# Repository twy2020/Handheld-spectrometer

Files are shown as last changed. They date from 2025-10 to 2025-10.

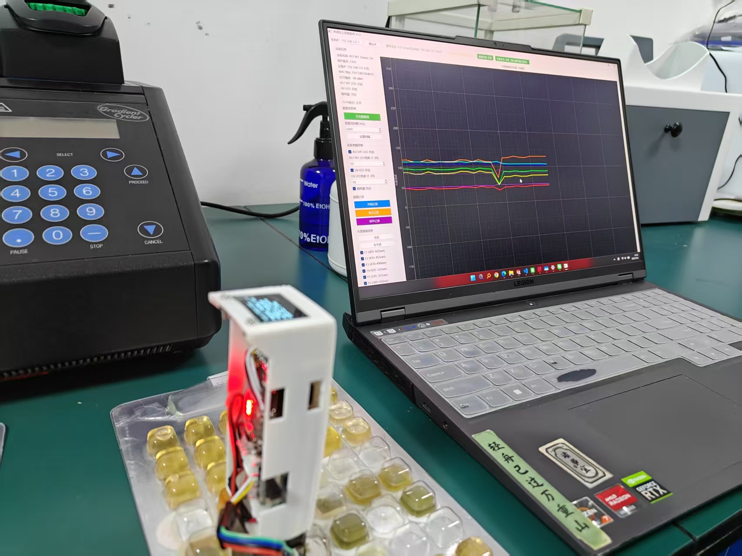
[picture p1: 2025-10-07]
pic/test_2.jpg

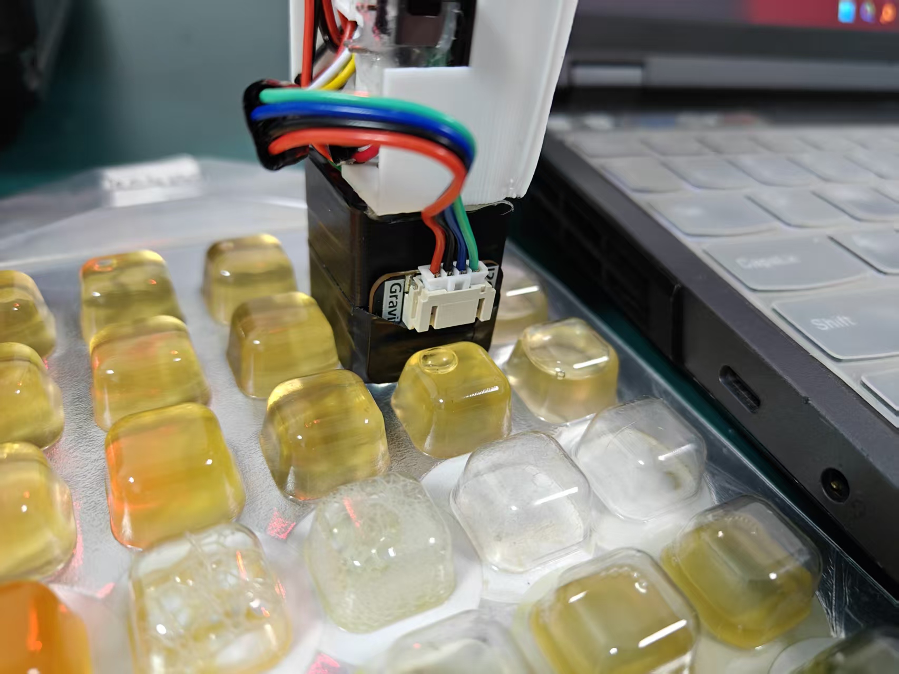
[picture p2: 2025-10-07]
pic/test_1.jpg

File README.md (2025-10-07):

# Smart Spectrometer System - Setup and Usage Guide
[README-中文](https://github.com/twy2020/Handheld-spectrometer/blob/main/README-CN.md)
## 1. Hardware Components List

Please prepare the following modules required for setup according to this list:

| Component | Model/Specification | Description |
| :--- | :--- | :--- |
| Spectral Sensor | RFRobot AS7341 (with built-in LED) | 11-channel visible light spectral sensor, including 8 optical channels, 1 clear channel, and 1 near-infrared channel |
| Main Controller | ESP32C3 Super Mini | Single-core processor with integrated WiFi (Required) |
| Display | SSD1306 128×64 OLED | Displays real-time spectral data, system status, and menu interface |
| UV Illumination System | UV LED 365nm x3 | Provides stable auxiliary light source for detection |
| UV LED Driver Board | CN5711 PWM LED Driver Board | Used to drive and adjust UV LEDs |
| Buzzer | Passive Buzzer (3.3V drive) | Optional, for device operation prompts |
| Power Bank | 3.7V Lithium Polymer Battery | Provides offline power for the device |
| Type-C Charging Module | Any module supporting Type-C interface and 5V output | Provides universal Type-C charging functionality |
| Battery Charge/Discharge Management Module | Any module supporting LiPo battery charge/discharge | Manages charging and passthrough charging for the 3.7V battery |
| Connecting Wires | Suitable insulated wires | For electrical connections between modules |
| Circuit Substrate | Perfboard or Custom PCB | Choose the circuit carrier method based on needs |

## 2. Required Tools

**Essential Tools:**

- Soldering Iron, Solder Wire, Flux
- Wire Strippers, Scissors, Measuring Tools
- Hot Glue Gun
- Multimeter

**Optional Tools:**

- Oscilloscope (Non-essential)
- 3D Printer (Non-essential)

## 3. Hardware Assembly

### 3.1 Circuit Soldering

Please solder all components according to the module connection diagram.
hardware

### 3.2 Enclosure Fabrication

The "3D" directory in the project files contains two model files that can be used to create the device enclosure, enhancing the product-like appearance.
3D

## 4. Device Firmware Flashing

### 4.1 Software Environment Configuration

**Software to Install:**

1.  CH341 Serial Port Driver
2.  Arduino IDE

**Arduino IDE Installation Steps:**

-   Visit the official website to download the latest Arduino IDE: https://www.arduino.cc/en/software
-   Install and launch the Arduino application
-   Add ESP32 board support

**Method for Adding ESP32 Board:**

1.  Go to File → Preferences
2.  Add the following URL in "Additional Boards Manager URLs":
    ```
    https://raw.githubusercontent.com/espressif/arduino-esp32/gh-pages/package_esp32_index.json
    ```
3.  Go to Tools → Board → ESP32 Arduino, select "ESP32C3 Dev Module"
4.  Go to Tools → Port, select the serial port corresponding to the ESP32C3 SuperMini
5.  **Important**: Go to Tools → USB CDC On Boot, set it to "Enable" (otherwise USB serial communication will not work)

### 4.2 Firmware Flashing Steps

1.  Open the `Spectrometer_v2.ino` file from the project using Arduino IDE
2.  Connect the ESP32C3 Super Mini to the computer via a USB cable
3.  Select the correct Port and Board type (ESP32C3 Dev Module)
4.  Click the "Upload" button and wait for the process to complete

## 5. PC Software Installation

### 5.1 Python Environment Configuration

**Installation Method 1: From Python Official Website**

-   Download and install Python 3.12: https://www.python.org/downloads/release/python-3120/

**Installation Method 2: Via Anaconda**

-   Download Anaconda: https://www.anaconda.com/download

**Note**: Please ensure that Python or Conda has been added to the system environment variables so they can be used directly in the terminal.

### 5.2 Installing Dependencies

**Installation using Conda environment:**

```bash
conda create -n SpDevice-PC python=3.12
conda activate SpDevice-PC
pip install PyQT5 pyqtgraph pyqt5-tools pandas
```

**Installation using Python environment:**

```bash
pip install PyQT5 pyqtgraph pyqt5-tools pandas
```

### 5.3 Starting the Software

Run the following command in the configured Conda environment or system Python environment:

```bash
python Spectrometer_v2_PC.py
```

## 6. Device Usage Instructions

### 6.1 Basic Operation

The device can directly collect and display real-time spectral data on the OLED screen.
device_data

### 6.2 Advanced Features

To use more features, please connect to the PC software via WiFi. Please refer to the software manual for detailed operations.

---

**Note**: If you have any questions during the setup and usage process, please refer to the project documentation or contact the author via email: tenwonyun@gmail.com

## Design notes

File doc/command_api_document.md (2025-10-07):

# AS7341 Spectral Sensor Device Communication Protocol Documentation

## 1. Device Basic Information

- **Device Name**: AS7341_Sensor_Device
- **Device Type**: Spectral_Sensor
- **Firmware Version**: 2.0.0
- **Communication Protocol**: TCP + UDP

## 2. Communication Port Configuration

| Port | Protocol | Purpose | Direction |
| ---- | --- | --- | --- |
| 6677 | TCP | Target server connection, data stream control | Bidirectional |
| 6688 | TCP | Command server, device control | Bidirectional |
| 6699 | UDP | Data stream transmission | Device → Host |

## 3. Command Format

All commands are in JSON format and sent via TCP port 6688.

### 3.1 Basic Command Structure

```json
{
  "command": "value",
  "parameter": value
}
```

## 4. Device Control Commands

### 4.1 Data Stream Mode Control

#### Enter Data Stream Mode

```json
{"dataStream": true}
```

#### Exit Data Stream Mode

```json
{"dataStream": false}
```

### 4.2 Data Stream Transmission Control

#### Set Continuous Transmission Mode

```json
{"streamMode": "continuous"}
```

#### Set Fixed Count Transmission Mode

```json
{
  "streamMode": "fixed",
  "streamCount": 100
}
```

#### Set Transmission Count Separately

```json
{"streamCount": 50}
```

#### Pause Data Stream Transmission

```json
{"streamPause": true}
```

#### Resume Data Stream Transmission

```json
{"streamPause": false}
```

#### Reset Transmission Count

```json
{"streamReset": true}
```

#### Set Transmission Interval

```json
{"streamInterval": 200}
```

- Minimum interval: 400ms
- Unit: milliseconds

### 4.3 Device Hardware Control

#### AS7341 LED Control

```json
{"as7341Led": true}
```

```json
{"as7341Led": false}
```

#### AS7341 LED Brightness Setting

```json
{"as7341Brightness": 15}
```

- Range: 1-20

#### UV LED Control

```json
{"uvLed": true}
```

```json
{"uvLed": false}
```

#### UV LED Brightness Setting

```json
{"uvBrightness": 10}
```

- Range: 1-20

#### Buzzer Control

```json
{"buzzer": true}
```

```json
{"buzzer": false}
```

### 4.4 System Commands

#### Get Device Status

```json
{"getDeviceStatus": true}
```

#### Device Reboot

```json
{"reboot": true}
```

## 5. Response Mechanism

### 5.1 Command Response Format

All commands receive JSON format responses:

```json
{"response": "OK"}
```

Or error responses:

```json
{"response": "ERROR: error_message"}
```

### 5.2 Response Timing

- Responses are returned immediately after command processing
- Responses are returned via the original TCP connection
- Non-blocking queue mechanism is used to avoid affecting UDP data streams

## 6. Data Stream Format

### 6.1 UDP Data Stream Format

Sent via UDP port 6699, JSON format:

```json
{
  "t": 1234567890,
  "d": [415, 230, 180, 320, 280, 195, 165, 210],
  "c": 1502,
  "sc": 10
}
```

**Field Description**:

- `t`: Timestamp (milliseconds)
- `d`: Spectral data array [F1, F2, F3, F4, F5, F6, F7, F8]
- `c`: Total packet count
- `sc`: Current stream count (fixed count mode only)

### 6.2 Data Stream Statistics

Statistics output via serial port every 500 packets:

```
UDP Packet Count: 500 (10/10)
```

## 7. Device Status Information

### 7.1 Automatic Transmission Triggers

Device status is automatically sent in the following situations:

1. When target server (6677) connection is established
2. When receiving `{"getDeviceStatus": true}` command
3. When device parameters change (LED, brightness, etc.)

### 7.2 Device Status Format

```json
{
  "type": "deviceStatus",
  "device": "AS7341_Sensor_Device",
  "timestamp": 178162,
  "status": {
    "as7341_led": true,
    "as7341_bright": 1,
    "uv_led": false,
    "uv_bright": 20,
    "buzzer": false,
    "sensor": true,
    "stream_mode": "fixed",
    "stream_paused": true,
    "packet_count": 33,
    "interval": 100,
    "current_count": 10,
    "target_count": 10,
    "remaining": 0
  }
}
```

**Status Field Description**:

- `as7341_led`: AS7341 LED on/off status
- `as7341_bright`: AS7341 LED brightness (1-20)
- `uv_led`: UV LED on/off status
- `uv_bright`: UV LED brightness (1-20)
- `buzzer`: Buzzer on/off status
- `sensor`: Sensor initialization status
- `stream_mode`: Data stream mode ("continuous" | "fixed")
- `stream_paused`: Data stream pause status
- `packet_count`: Total packet count
- `interval`: Data stream interval (ms)
- `current_count`: Current stream count
- `target_count`: Target stream count
- `remaining`: Remaining count

## 8. Connection Status Notifications

### 8.1 Connection Established Notification

```json
{
  "type": "connection",
  "status": "connected",
  "device": "AS7341_Sensor_Device",
  "timestamp": 1234567890,
  "ip": "192.168.1.100",
  "rssi": -65,
  "status": {
    "as7341_led": true,
    "as7341_bright": 12,
    "uv_led": true,
    "uv_bright": 8,
    "buzzer": true,
    "sensor": true
  }
}
```

### 8.2 Connection Disconnected Notification

```json
{
  "type": "connection",
  "status": "disconnected",
  "device": "AS7341_Sensor_Device",
  "timestamp": 1234567890,
  "status": {
    "as7341_led": true,
    "as7341_bright": 12,
    "uv_led": true,
    "uv_bright": 8,
    "buzzer": true,
    "sensor": true
  }
}
```

## 9. Completion Notifications

### 9.1 Data Stream Completion Notification

```json
{
  "type": "streamComplete",
  "device": "AS7341_Sensor_Device",
  "timestamp": 135964,
  "total_packets": 24,
  "stream_mode": "fixed",
  "target_count": 10,
  "actual_count": 10,
  "status": "completed"
}
```

## 10. Error Handling

### 10.1 Common Error Responses

```json
{"response": "ERROR: JSON parse failed"}
{"response": "ERROR: Cannot enter data stream mode"}
{"response": "ERROR: Invalid stream count"}
{"response": "ERROR: Interval too small"}
{"response": "ERROR: Sensor read failed"}
```

### 10.2 Error Handling Mechanism

- Invalid commands return error responses
- Sensor read failures trigger retries
- Network disconnections automatically reconnect (max retries: 3)

## 11. Usage Examples

### 11.1 Complete Workflow

```json
// 1. Get device status
{"getDeviceStatus": true}

// 2. Configure device parameters
{
  "as7341Led": true,
  "as7341Brightness": 15,
  "uvLed": false,
  "streamInterval": 200
}

// 3. Enter data stream mode
{"dataStream": true}

// 4. Set fixed count transmission
{
  "streamMode": "fixed",
  "streamCount": 100
}

// 5. Pause transmission
{"streamPause": true}

// 6. Modify parameters and resume
{
  "as7341Brightness": 10,
  "streamPause": false
}

// 7. Exit data stream mode
{"dataStream": false}
```

### 11.2 Quick Start Data Stream

```json
{
  "dataStream": true,
  "streamMode": "continuous",
  "as7341Led": true,
  "as7341Brightness": 10,
  "streamInterval": 300
}
```

## 12. Important Notes

1. **Connection Order**: Recommended to establish TCP connection first, then send control commands
2. **UDP Stability**: TCP responses use queue mechanism to avoid affecting UDP data streams
3. **Command Frequency**: Avoid sending commands at high frequency (minimum interval recommended: 100ms)
4. **Data Stream Interval**: Minimum interval 400ms, smaller intervals may cause data loss
5. **Network Requirements**: Ensure ports 6677, 6688, 6699 are accessible
6. **Timeout Handling**: Command connection timeout is 30 seconds, automatic disconnection after timeout
7. **Error Recovery**: Device automatically attempts reconnection, host should handle connection interruptions

## 13. Serial Debug Information

Device outputs debug information via serial port (baud rate 115200):

- Command reception and processing status
- Data stream statistics (every 500 packets)
- Connection status changes
- Error information

## 14. Version History

- v2.0.0: Support for data stream modes, device control, status queries
- Added continuous and fixed count transmission modes
- Optimized network communication stability
- Non-blocking response mechanism

---

**Document Version**: 1.0  
**Last Updated**: 2025-09-20  
**Corresponding Firmware Version**: 2.0.0

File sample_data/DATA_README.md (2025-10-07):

# Spectrometer Data Analysis for *Pseudomonas aeruginosa* Culture

## Project Overview
This project involves the analysis of spectral data obtained from a 96-well plate culture substrate of *Pseudomonas aeruginosa*. Measurements were conducted using a Handheld Spectrometer over a total period of 9 hours. The data from the latter ~6 hours (recorded at one-minute intervals) was retained for detailed analysis.

## Files in `sample_data`

The `sample_data` directory contains three primary files:

1.  **`measurement_session_20251005_153547.csv`**
    *   This file contains the raw data captured by our in-house developed Handheld Spectrometer and its accompanying host computer software.

2.  **`process.py`**
    *   This is a specialized Python script designed for filtering the spectral data and generating plots/charts.

3.  **`result.png`**
    *   This figure presents a comparative analysis of the substrate spectral change curves, measured under three different illumination modes: **ONLY LED**, **ONLY UV**, and **LED_UV**.

## Known Issues & Notes
We identified a synchronization issue in the device's timed measurement mechanism. Some repeated measurements returned values of zero, which is attributed to a lack of synchronization with the light source.

Despite this issue, observable patterns can still be discerned from the extensive set of redundant measurement data.

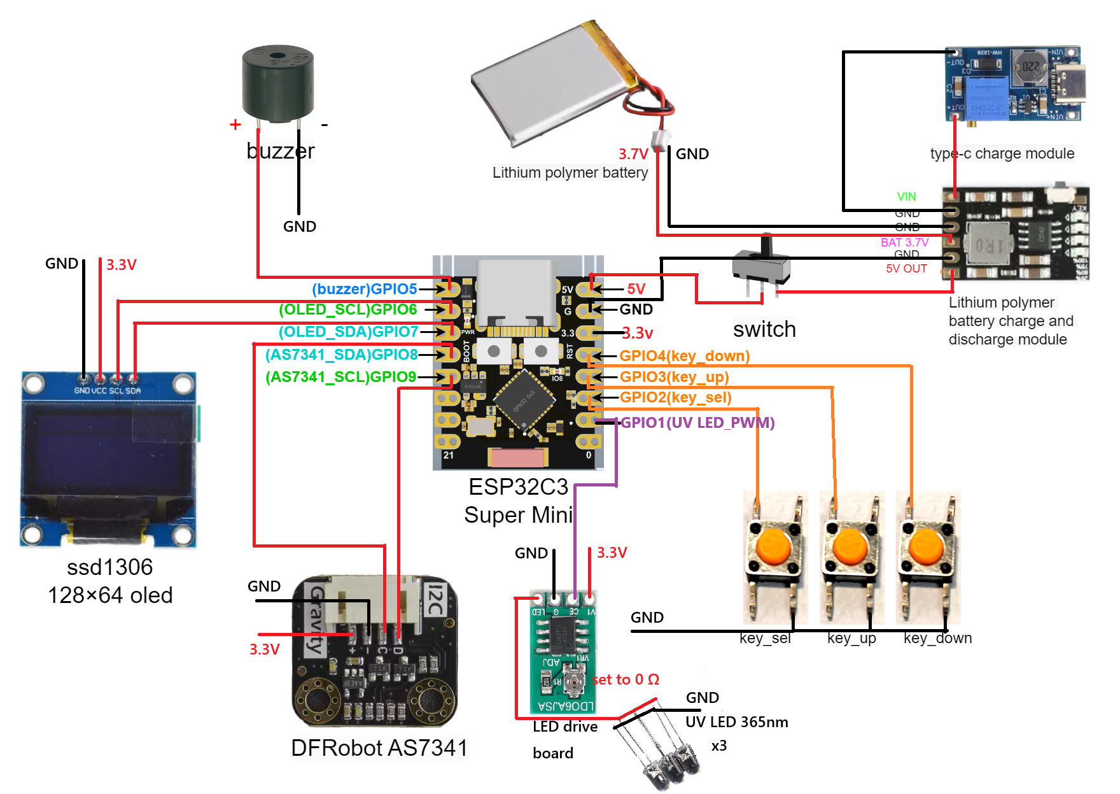
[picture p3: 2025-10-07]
pic/Hardware.png

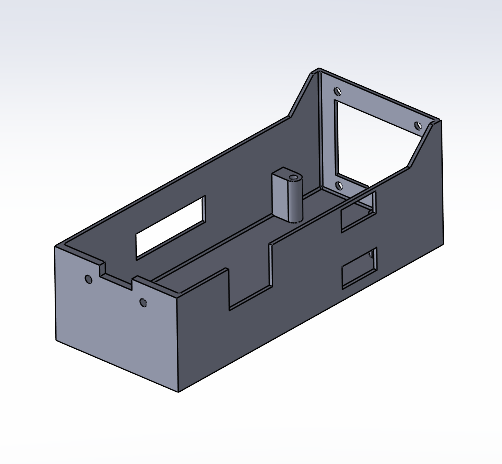
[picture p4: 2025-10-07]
pic/body.png

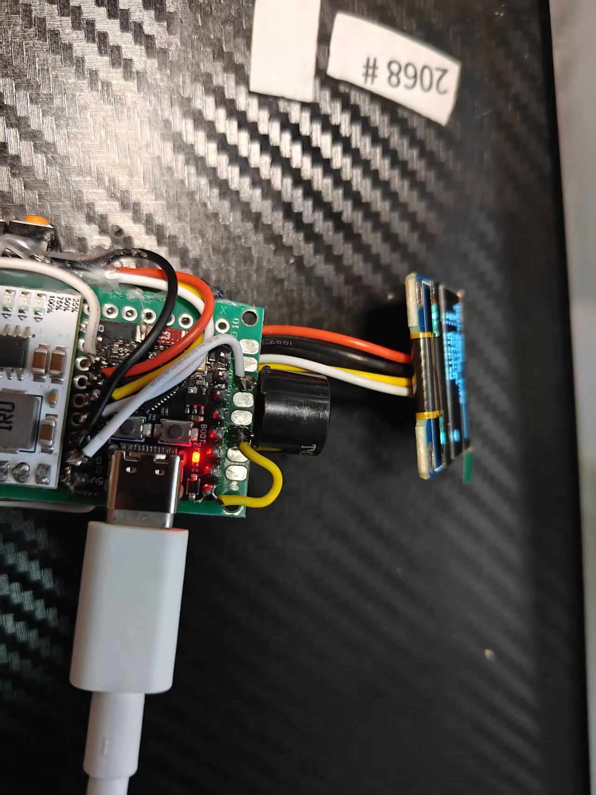
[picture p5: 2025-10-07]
pic/work_8.jpg

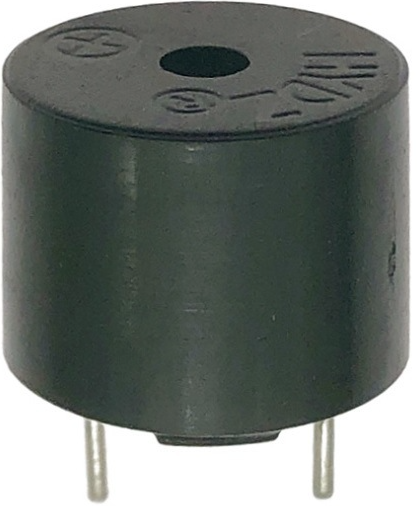
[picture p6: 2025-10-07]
pic/buzzer.png

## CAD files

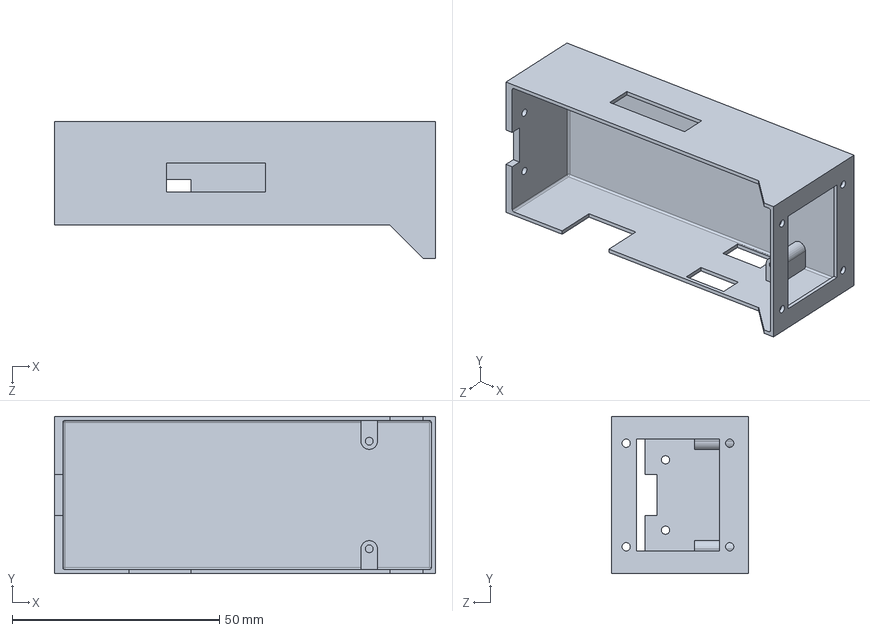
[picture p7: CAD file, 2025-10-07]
3D/body.SLDPRT
92.0 x 38.0 x 33.0 mm

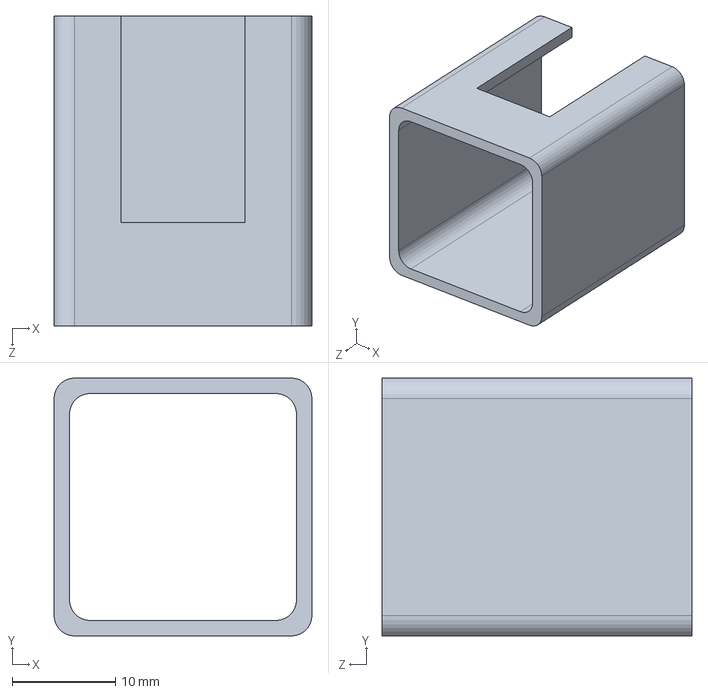
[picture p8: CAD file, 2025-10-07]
3D/head.SLDPRT
25.0 x 25.0 x 30.0 mm

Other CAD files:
3D/body.STL
3D/head.STL

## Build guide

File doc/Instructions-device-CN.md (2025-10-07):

# AS7341光谱仪设备使用说明书

## 1. 产品概述

AS7341光谱仪设备是一款基于ESP32的多功能光谱测量仪器，集成了AS7341光谱传感器、OLED显示屏、UV LED、蜂鸣器等组件，支持本地操作和远程数据流传输两种工作模式。

### 主要特性

- **光谱测量**：8通道光谱数据采集（F1-F8）
- **双工作模式**：本地显示模式 + 数据流传输模式
- **无线通信**：WiFi连接，支持TCP指令控制和UDP数据流传输
- **本地控制**：OLED菜单 + 三按键操作
- **可编程光源**：AS7341内置LED和外部UV LED，亮度可调
- **状态指示**：蜂鸣器声音反馈

## 2. 硬件规格

### 2.1 硬件接口

- **OLED显示屏**：128×64分辨率，显示菜单和光谱数据
- **控制按键**：
  - UP键：向上选择/增加数值
  - SEL键：确认/进入菜单
  - DOWN键：向下选择/减少数值
- **传感器**：AS7341 11通道光谱传感器
- **光源**：
  - AS7341内置LED（可调亮度）
  - 外部UV LED（可调亮度）
- **音频**：压电蜂鸣器（可调音量）

### 2.2 通信接口

- **WiFi**：2.4GHz IEEE 802.11 b/g/n
- **指令端口**：TCP 6688（JSON格式指令）
- **数据流端口**：UDP 6699（光谱数据流）
- **目标服务器端口**：TCP 6677（状态通知）
- **USB串口**：波特率 115200 （开发调试）

## 3. 快速开始

### 3.1 设备启动

1. 连接电源（Micro-USB）
2. 设备自动启动，显示初始化界面
3. 进入默认的光谱显示模式

### 3.2 基本操作

- **短按SEL键**：进入主菜单
- **UP/DOWN键**：在菜单中导航
- **长按SEL键**：返回上一级菜单

## 4. 菜单系统详解

### 4.1 光谱显示模式（默认）

设备启动后自动进入此模式，显示三页信息：

**页面1 - 光谱数据**

- 实时显示8个光谱通道的数值
- F1-F4显示在左侧，F5-F8显示在右侧

**页面2 - 系统状态**

- AS7341传感器状态
- AS7341 LED状态
- UV LED状态  
- 蜂鸣器状态

**页面3 - WiFi状态**

- WiFi使能状态
- 连接状态（已连接/连接中/未连接）
- SSID信息
- IP地址信息
- 重连状态

### 4.2 主菜单选项

#### 1. AS7341控制

- **LED亮度**：1-20级可调，UP增加，DOWN减少
- **LED开关**：UP开启，DOWN关闭

#### 2. UV LED控制

- **UV亮度**：1-20级可调
- **UV开关**：UP开启，DOWN关闭

#### 3. 蜂鸣器控制

- **音量调节**：1-10级可调
- **蜂鸣器开关**：UP开启，DOWN关闭

#### 4. WiFi设置

**WiFi SSID**：设置无线网络名称
**WiFi密码**：设置无线网络密码
**固定IP**：设置设备静态IP（可选，留空使用DHCP）
**目标IP**：设置数据接收服务器IP地址
**WiFi开关**：启用/禁用WiFi功能
**手动重连**：立即重新连接WiFi

#### 5. 退出

返回光谱显示模式

## 5. WiFi设置详细说明

### 5.1 编辑模式操作

进入任意编辑项目（SSID、密码、IP地址）：

**字符选择模式**：

- UP/DOWN：切换字符
- SEL：确认选择当前字符
- 长按SEL：保存并退出

**编辑模式**（长按UP进入）：

- UP：光标右移
- DOWN：光标左移  
- SEL：删除光标前字符
- 长按DOWN：退出编辑模式

### 5.2 连接状态指示

- **连接中**：显示"Connecting"
- **已连接**：显示IP地址和信号强度
- **连接失败**：显示重试次数和最大重连次数
- **超过重试限制**：显示"Max retries reached"

## 6. 数据流模式

### 6.1 进入数据流模式

**前提条件**：

- WiFi已连接
- 目标IP已正确设置
- 传感器初始化成功

**进入方式**：
通过TCP指令发送：`{"dataStream": true}`

### 6.2 数据流模式显示

在数据流模式下，OLED显示：

- 数据包计数
- 实时发送频率（FPS）
- 发送模式（持续/指定次数）
- 当前计数/目标计数（指定次数模式）
- 发送状态（运行中/暂停）
- 发送间隔

### 6.3 数据流控制指令

**发送模式设置**：

```json
{"streamMode": "continuous"}  // 持续发送模式
{"streamMode": "fixed", "streamCount": 1000}  // 指定次数模式
```

**单独设置发送次数**：

```json
{"streamCount": 500}
```

**退出数据流模式**：

```json
{"dataStream": false}
```

## 7. 远程控制指令

### 7.1 设备控制指令

**AS7341 LED控制**：

```json
{"as7341Led": true}  // 开启
{"as7341Led": false} // 关闭
{"as7341Brightness": 15}  // 设置亮度(1-20)
```

**UV LED控制**：

```json
{"uvLed": true}      // 开启
{"uvLed": false}     // 关闭  
{"uvBrightness": 10} // 设置亮度(1-20)
```

**蜂鸣器控制**：

```json
{"buzzer": true}     // 开启
{"buzzer": false}    // 关闭
```

**设备状态查询**：

```json
{"getDeviceStatus": true}
```

**设备重启**：

```json
{"reboot": true}
```

### 7.2 指令响应

设备对每个指令都会返回JSON格式响应：

```json
{"response": "OK"}
{"response": "ERROR: 错误信息"}
```

## 8. 数据格式说明

### 8.1 光谱数据格式（UDP）

```json
{
  "t": 123456789,      // 时间戳(ms)
  "d": [123,456,789,...], // 8通道光谱数据
  "c": 1000,           // 数据包计数
  "sc": 50             // 当前发送计数（指定次数模式）
}
```

### 8.2 设备状态格式

```json
{
  "type": "deviceStatus",
  "device": "AS7341_Sensor_Device",
  "timestamp": 123456789,
  "status": {
    "as7341_led": true,
    "as7341_bright": 10,
    "uv_led": false, 
    "uv_bright": 15,
    "buzzer": true,
    "sensor": true,
    "stream_mode": "continuous",
    "stream_paused": false,
    "packet_count": 1000,
    "interval": 100,
    "current_count": 500,
    "target_count": 1000
  }
}
```

### 8.3 连接状态通知

```json
{
  "type": "connection", 
  "status": "connected",
  "device": "AS7341_Sensor_Device",
  "timestamp": 123456789,
  "ip": "192.168.1.100",
  "rssi": -65
}
```

### 8.4 数据流完成通知

```json
{
  "type": "streamComplete",
  "device": "AS7341_Sensor_Device", 
  "timestamp": 123456789,
  "total_packets": 5000,
  "stream_mode": "fixed",
  "target_count": 5000,
  "actual_count": 5000,
  "status": "completed"
}
```

## 9. 故障排除

### 9.1 常见问题

**WiFi连接失败**：

- 检查SSID和密码是否正确
- 确认路由器2.4GHz频段可用
- 检查信号强度
- 尝试手动重连功能

**传感器读数异常**：

- 检查传感器连接
- 确认环境光照条件合适
- 重启设备

**数据流发送失败**：

- 确认目标IP和端口正确
- 检查网络连通性
- 确认接收端服务正常运行

**设备无响应**：

- 检查电源供电
- 尝试硬件重启
- 检查USB连接线

### 9.2 状态指示灯

- **启动音**：一声蜂鸣表示启动成功
- **操作音**：短蜂鸣表示按键操作
- **错误音**：两声短蜂鸣表示操作错误
- **连接音**：启动时WiFi连接成功提示

## 10. 技术参数

- **工作电压**：5V DC（USB供电）
- **工作电流**：待机<100mA，工作峰值<300mA
- **光谱范围**：400-700nm（8个通道）
- **ADC分辨率**：16位
- **数据输出率**：最高100Hz（可配置）
- **工作温度**：0-40℃
- **存储温度**：-20-60℃
- **WiFi标准**：IEEE 802.11 b/g/n

## 11. 维护与保养

- 保持传感器窗口清洁
- 避免强光直射传感器
- 定期检查固件更新
- 避免潮湿和高温环境
- 使用原装电源适配器

---

**技术支持**：如遇问题，请记录设备显示的异常信息并联系技术支持人员（Teng email:tenwonyun@gmail.com）。

**版本信息**：本说明书对应固件版本 v2.0.0

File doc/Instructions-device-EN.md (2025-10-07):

# AS7341 Spectrometer Device User Manual

## 1. Product Overview

The AS7341 Spectrometer Device is a multi-functional spectral measurement instrument based on ESP32, integrating AS7341 spectral sensor, OLED display, UV LED, buzzer and other components. It supports two operation modes: local operation and remote data stream transmission.

### Key Features

- **Spectral Measurement**: 8-channel spectral data acquisition (F1-F8)
- **Dual Operation Modes**: Local display mode + Data stream transmission mode
- **Wireless Communication**: WiFi connectivity, supporting TCP command control and UDP data stream transmission
- **Local Control**: OLED menu + Three-button operation
- **Programmable Light Sources**: AS7341 built-in LED and external UV LED with adjustable brightness
- **Status Indication**: Buzzer audio feedback

## 2. Hardware Specifications

### 2.1 Hardware Interfaces

- **OLED Display**: 128×64 resolution, displaying menu and spectral data
- **Control Buttons**:
  - UP Button: Navigate up/Increase value
  - SEL Button: Confirm/Enter menu
  - DOWN Button: Navigate down/Decrease value
- **Sensor**: AS7341 11-channel spectral sensor
- **Light Sources**:
  - AS7341 built-in LED (adjustable brightness)
  - External UV LED (adjustable brightness)
- **Audio**: Piezo buzzer (adjustable volume)

### 2.2 Communication Interfaces

- **WiFi**: 2.4GHz IEEE 802.11 b/g/n
- **Command Port**: TCP 6688 (JSON format commands)
- **Data Stream Port**: UDP 6699 (Spectral data stream)
- **Target Server Port**: TCP 6677 (Status notifications)
- **USB Serial**: Baud rate 115200 (Development debugging)

## 3. Quick Start

### 3.1 Device Startup

1. Connect power supply (Micro-USB)
2. Device automatically boots up, showing initialization screen
3. Enters default spectral display mode

### 3.2 Basic Operations

- **Short press SEL button**: Enter main menu
- **UP/DOWN buttons**: Navigate through menu
- **Long press SEL button**: Return to previous menu level

## 4. Menu System Details

### 4.1 Spectral Display Mode (Default)

Device automatically enters this mode upon startup, displaying three pages:

**Page 1 - Spectral Data**

- Real-time display of 8 spectral channel values
- F1-F4 shown on left side, F5-F8 shown on right side

**Page 2 - System Status**

- AS7341 sensor status
- AS7341 LED status
- UV LED status
- Buzzer status

**Page 3 - WiFi Status**

- WiFi enable status
- Connection status (Connected/Connecting/Not connected)
- SSID information
- IP address information
- Reconnection status

### 4.2 Main Menu Options

#### 1. AS7341 Control

- **LED Brightness**: 1-20 levels adjustable, UP increases, DOWN decreases
- **LED Switch**: UP turns on, DOWN turns off

#### 2. UV LED Control

- **UV Brightness**: 1-20 levels adjustable
- **UV Switch**: UP turns on, DOWN turns off

#### 3. Buzzer Control

- **Volume Adjustment**: 1-10 levels adjustable
- **Buzzer Switch**: UP turns on, DOWN turns off

#### 4. WiFi Settings

**WiFi SSID**: Set wireless network name
**WiFi Password**: Set wireless network password
**Static IP**: Set device static IP (Optional, leave blank for DHCP)
**Target IP**: Set data receiving server IP address
**WiFi Switch**: Enable/disable WiFi function
**Manual Reconnect**: Immediately reconnect to WiFi

#### 5. Exit

Return to spectral display mode

## 5. WiFi Settings Detailed Instructions

### 5.1 Edit Mode Operations

Enter any editing item (SSID, password, IP address):

**Character Selection Mode**:

- UP/DOWN: Switch characters
- SEL: Confirm selection of current character
- Long press SEL: Save and exit

**Edit Mode** (Enter by long pressing UP):

- UP: Move cursor right
- DOWN: Move cursor left
- SEL: Delete character before cursor
- Long press DOWN: Exit edit mode

### 5.2 Connection Status Indication

- **Connecting**: Shows "Connecting"
- **Connected**: Shows IP address and signal strength
- **Connection Failed**: Shows retry count and maximum reconnection attempts
- **Exceeded Retry Limit**: Shows "Max retries reached"

## 6. Data Stream Mode

### 6.1 Entering Data Stream Mode

**Prerequisites**:

- WiFi connected
- Target IP correctly set
- Sensor initialized successfully

**Entry Method**:
Send via TCP command: `{"dataStream": true}`

### 6.2 Data Stream Mode Display

In data stream mode, OLED displays:

- Data packet count
- Real-time transmission frequency (FPS)
- Transmission mode (Continuous/Specified count)
- Current count/Target count (Specified count mode)
- Transmission status (Running/Paused)
- Transmission interval

### 6.3 Data Stream Control Commands

**Transmission Mode Settings**:

```json
{"streamMode": "continuous"}  // Continuous transmission mode
{"streamMode": "fixed", "streamCount": 1000}  // Specified count mode
```

**Set Transmission Count Separately**:

```json
{"streamCount": 500}
```

**Exit Data Stream Mode**:

```json
{"dataStream": false}
```

## 7. Remote Control Commands

### 7.1 Device Control Commands

**AS7341 LED Control**:

```json
{"as7341Led": true}  // Turn on
{"as7341Led": false} // Turn off
{"as7341Brightness": 15}  // Set brightness (1-20)
```

**UV LED Control**:

```json
{"uvLed": true}      // Turn on
{"uvLed": false}     // Turn off
{"uvBrightness": 10} // Set brightness (1-20)
```

**Buzzer Control**:

```json
{"buzzer": true}     // Turn on
{"buzzer": false}    // Turn off
```

**Device Status Query**:

```json
{"getDeviceStatus": true}
```

**Device Reboot**:

```json
{"reboot": true}
```

### 7.2 Command Responses

Device returns JSON format response for each command:

```json
{"response": "OK"}
{"response": "ERROR: Error message"}
```

## 8. Data Format Specifications

### 8.1 Spectral Data Format (UDP)

```json
{
  "t": 123456789,      // Timestamp (ms)
  "d": [123,456,789,...], // 8-channel spectral data
  "c": 1000,           // Data packet count
  "sc": 50             // Current transmission count (specified count mode)
}
```

### 8.2 Device Status Format

```json
{
  "type": "deviceStatus",
  "device": "AS7341_Sensor_Device",
  "timestamp": 123456789,
  "status": {
    "as7341_led": true,
    "as7341_bright": 10,
    "uv_led": false,
    "uv_bright": 15,
    "buzzer": true,
    "sensor": true,
    "stream_mode": "continuous",
    "stream_paused": false,
    "packet_count": 1000,
    "interval": 100,
    "current_count": 500,
    "target_count": 1000
  }
}
```

### 8.3 Connection Status Notification

```json
{
  "type": "connection",
  "status": "connected",
  "device": "AS7341_Sensor_Device",
  "timestamp": 123456789,
  "ip": "192.168.1.100",
  "rssi": -65
}
```

### 8.4 Data Stream Completion Notification

```json
{
  "type": "streamComplete",
  "device": "AS7341_Sensor_Device",
  "timestamp": 123456789,
  "total_packets": 5000,
  "stream_mode": "fixed",
  "target_count": 5000,
  "actual_count": 5000,
  "status": "completed"
}
```

## 9. Troubleshooting

### 9.1 Common Issues

**WiFi Connection Failure**:

- Check if SSID and password are correct
- Confirm router 2.4GHz band is available
- Check signal strength
- Try manual reconnect function

**Abnormal Sensor Readings**:

- Check sensor connection
- Confirm appropriate ambient lighting conditions
- Restart device

**Data Stream Transmission Failure**:

- Confirm target IP and port are correct
- Check network connectivity
- Confirm receiving end service is running properly

**Device Unresponsive**:

- Check power supply
- Try hardware restart
- Check USB cable connection

### 9.2 Status Indicator Sounds

- **Startup Sound**: Single beep indicates successful startup
- **Operation Sound**: Short beep indicates button operation
- **Error Sound**: Two short beeps indicate operation error
- **Connection Sound**: WiFi connection success prompt during startup

## 10. Technical Parameters

- **Operating Voltage**: 5V DC (USB power supply)
- **Operating Current**: Standby <100mA, Peak operation <300mA
- **Spectral Range**: 400-700nm (8 channels)
- **ADC Resolution**: 16-bit
- **Data Output Rate**: Up to 100Hz (configurable)
- **Operating Temperature**: 0-40℃
- **Storage Temperature**: -20-60℃
- **WiFi Standard**: IEEE 802.11 b/g/n

## 11. Maintenance and Care

- Keep sensor window clean
- Avoid direct strong light exposure to sensor
- Regularly check for firmware updates
- Avoid humid and high temperature environments
- Use original power adapter

---

**Technical Support**: If encountering problems, please record the abnormal information displayed by the device and contact technical support personnel (Teng email:tenwonyun@gmail.com).

**Version Information**: This manual corresponds to firmware version v2.0.0

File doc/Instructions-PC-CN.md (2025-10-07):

# 光谱仪上位机软件使用说明书

## 软件概述

光谱仪上位机软件是一款用于控制和监控AS7341光谱仪设备的专业软件，支持实时数据采集、多模式测量、数据记录与分析等功能。软件采用PyQt5开发，具有友好的图形用户界面。

---

## 系统要求

### 硬件要求

- 推荐内存：4GB以上
- 存储空间：至少100MB可用空间
- 网络接口：支持TCP/UDP通信

### 软件要求

- 操作系统：Windows 7/10/11，Linux，macOS
- Python环境：Python 3.12
- 依赖库：PyQt5, pyqtgraph, pandas等

---

## 安装步骤

### 1. 安装Python环境

从Python官网下载并安装Python 3.7或更高版本。

### 2. 安装依赖库

```bash
pip install PyQt5 pyqtgraph pandas
```

### 3. 运行软件

```bash
python Spectrometer_v2_PC.py
```

---

## 界面功能详解

### 1. 顶部状态栏

- **本机IP设置**：设置软件运行的本地IP地址
- **服务状态**：显示TCP/UDP服务器运行状态
- **心跳状态**：显示与设备的心跳通信状态
- **数据传输**：显示光谱数据接收状态
- **设备状态**：显示设备连接状态
- **数据流状态**：显示数据流运行状态

### 2. 设备信息面板

显示连接的设备基本信息：

- 设备名称、固件版本、设备IP
- MAC地址、信号强度(RSSI)
- LED状态（AS7341 LED、UV LED）
- 蜂鸣器状态
- 数据流模式、状态和计数信息

### 3. 数据流控制

- **开启/关闭数据流**：控制设备数据流的启动和停止
- **数据流模式**：
  - 持续发送模式：设备持续发送数据
  - 指定次数模式：设备发送指定次数后停止
- **目标发送次数**：设置指定次数模式的目标值
- **暂停/继续**：临时暂停或恢复数据流
- **重置计数**：重置数据流计数器
- **数据流间隔**：设置数据发送间隔（最小400ms）

### 4. 定时测量控制（新增功能）

- **启用定时测量**：开启/关闭定时测量功能
- **测量总时长**：设置整个测量会话的总时长（1-1440分钟）
- **测量间隔**：设置每次测量的间隔时间（1-1440分钟）
- **立即测量**：手动触发单次测量
- **测量状态**：显示当前测量进度和状态

### 5. 设备参数控制

- **AS7341 LED控制**：开启/关闭AS7341 LED，调节亮度(1-20)
- **UV LED控制**：开启/关闭UV LED，调节亮度(1-20)
- **蜂鸣器控制**：开启/关闭蜂鸣器
- **获取设备状态**：手动请求设备状态信息
- **设备重启**：重启连接的光谱仪设备

### 6. 数据记录控制

- **开始记录**：开始记录接收到的光谱数据
- **停止记录**：停止数据记录
- **保存记录**：将记录的数据保存为CSV文件
- **清空数据**：清除所有缓存和记录数据
- **数据统计**：显示当前缓存和记录的数据点数

### 7. 光谱通道选择

- 8个光谱通道（F1-F8），对应不同波长范围
- 支持全选/全不选功能
- 可单独选择显示的通道

### 8. 横轴模式选择

- **数据序号**：以数据包计数为横轴
- **时间戳**：以时间戳为横轴

---

## 标签页功能

### 1. 实时数据标签页

显示实时光谱数据曲线，支持多通道同时显示。

### 2. LED Only数据标签页

显示仅开启LED时的测量数据平均值。

### 3. UV Only数据标签页

显示仅开启UV灯时的测量数据平均值。

### 4. LED+UV数据标签页

显示同时开启LED和UV灯时的测量数据平均值。

---

## 使用流程

### 1. 初始设置

1. 确认本机IP地址设置正确
2. 确保设备与电脑在同一网络
3. 启动软件，等待服务初始化完成

### 2. 设备连接

1. 设备开机后自动连接软件
2. 观察设备状态显示"在线"
3. 确认数据传输状态正常

### 3. 基本数据采集

1. 在"数据流控制"中开启数据流
2. 选择合适的数据流模式和间隔
3. 在"实时数据"标签页观察光谱曲线

### 4. 定时测量

1. 在"定时测量控制"中启用功能
2. 设置测量总时长和间隔
3. 点击"立即测量"或等待自动测量
4. 在各标签页查看测量结果

### 5. 数据记录与保存

1. 点击"开始记录"开始数据采集
2. 采集完成后点击"停止记录"
3. 使用"保存记录"将数据导出为CSV文件

---

## 高级功能

### 测量序列说明

每次测量包含三个阶段：

1. **LED Only**：仅开启AS7341 LED，采集5次数据
2. **UV Only**：仅开启UV LED，采集5次数据  
3. **LED+UV**：同时开启两种LED，采集5次数据

### 数据文件格式

保存的CSV文件包含以下字段：

- measurement_index：测量序号
- measurement_time：测量时间
- measurement_type：测量类型（LED Only/UV Only/LED+UV）
- data_index：数据点序号
- F1-F8：8个通道的光谱强度值

---

## 故障排除

### 常见问题

1. **设备无法连接**
   
   - 检查IP地址设置是否正确
   - 确认设备与电脑在同一网络
   - 检查防火墙设置

2. **数据接收中断**
   
   - 检查网络连接稳定性
   - 确认UDP端口6699未被占用
   - 重启软件和设备

3. **指令发送失败**
   
   - 检查TCP客户端连接状态
   - 确认设备指令服务器正常运行
   - 查看指令响应提示

4. **测量数据异常**
   
   - 检查LED状态设置
   - 确认设备传感器正常工作
   - 检查环境光照条件

---

## 注意事项

1. 确保设备固件版本(v2.0.0)与软件兼容
2. 数据流间隔不要设置过小，避免数据丢失
3. 定时测量期间保持设备稳定
4. 定期保存重要数据，避免意外丢失
5. 软件关闭前请先停止所有数据流和测量

---

## 技术支持

如遇问题，请提供以下信息：

1. 软件版本号
2. 设备型号和固件版本
3. 错误提示信息
4. 网络环境描述
5. 问题复现步骤

---

**注意**：本软件仅供专业用途，使用时请遵守相关安全规范，未经作者运行，禁止进行商业用途（作者Teng邮箱：tenwonyun@gmail.com）。

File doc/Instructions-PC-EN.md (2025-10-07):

# Spectrometer PC Software User Manual

## Software Overview

The Spectrometer PC Software is a professional application for controlling and monitoring AS7341 spectrometer devices, supporting real-time data acquisition, multi-mode measurement, data recording, and analysis functions. Developed with PyQt5, the software features a user-friendly graphical interface.

---

## System Requirements

### Hardware Requirements

- Recommended RAM: 4GB or above
- Storage Space: At least 100MB available space
- Network Interface: Supports TCP/UDP communication

### Software Requirements

- Operating System: Windows 7/10/11, Linux, macOS
- Python Environment: Python 3.12
- Dependencies: PyQt5, pyqtgraph, pandas, etc.

---

## Installation Steps

### 1. Install Python Environment

Download and install Python 3.7 or higher from the official Python website.

### 2. Install Dependencies

```bash
pip install PyQt5 pyqtgraph pandas
```

### 3. Run the Software

```bash
python Spectrometer_v2_PC.py
```

---

## Interface Functions Detailed Explanation

### 1. Top Status Bar

- **Local IP Setting**: Set the local IP address for software operation
- **Service Status**: Display TCP/UDP server running status
- **Heartbeat Status**: Display heartbeat communication status with device
- **Data Transmission**: Display spectral data reception status
- **Device Status**: Display device connection status
- **Data Stream Status**: Display data stream operation status

### 2. Device Information Panel

Display basic information of connected devices:

- Device name, firmware version, device IP
- MAC address, signal strength (RSSI)
- LED status (AS7341 LED, UV LED)
- Buzzer status
- Data stream mode, status, and count information

### 3. Data Stream Control

- **Start/Stop Data Stream**: Control device data stream start and stop
- **Data Stream Modes**:
  - Continuous transmission mode: Device continuously sends data
  - Specified count mode: Device stops after sending specified count
- **Target Transmission Count**: Set target value for specified count mode
- **Pause/Resume**: Temporarily pause or resume data stream
- **Reset Count**: Reset data stream counter
- **Data Stream Interval**: Set data transmission interval (minimum 400ms)

### 4. Timed Measurement Control (New Feature)

- **Enable Timed Measurement**: Turn on/off timed measurement function
- **Total Measurement Duration**: Set total duration for entire measurement session (1-1440 minutes)
- **Measurement Interval**: Set interval time between each measurement (1-1440 minutes)
- **Immediate Measurement**: Manually trigger single measurement
- **Measurement Status**: Display current measurement progress and status

### 5. Device Parameter Control

- **AS7341 LED Control**: Turn on/off AS7341 LED, adjust brightness (1-20)
- **UV LED Control**: Turn on/off UV LED, adjust brightness (1-20)
- **Buzzer Control**: Turn on/off buzzer
- **Get Device Status**: Manually request device status information
- **Device Reboot**: Restart connected spectrometer device

### 6. Data Recording Control

- **Start Recording**: Begin recording received spectral data
- **Stop Recording**: Stop data recording
- **Save Recording**: Save recorded data as CSV file
- **Clear Data**: Clear all cached and recorded data
- **Data Statistics**: Display current cached and recorded data points count

### 7. Spectral Channel Selection

- 8 spectral channels (F1-F8), corresponding to different wavelength ranges
- Support select all/deselect all functions
- Individual channel display selection available

### 8. X-axis Mode Selection

- **Data Sequence**: Use data packet count as X-axis
- **Timestamp**: Use timestamp as X-axis

---

## Tab Functions

### 1. Real-time Data Tab

Display real-time spectral data curves, supporting multi-channel simultaneous display.

### 2. LED Only Data Tab

Display average measurement data when only LED is turned on.

### 3. UV Only Data Tab

Display average measurement data when only UV light is turned on.

### 4. LED+UV Data Tab

Display average measurement data when both LED and UV light are turned on.

---

## Usage Workflow

### 1. Initial Setup

1. Confirm local IP address is correctly set
2. Ensure device and computer are on the same network
3. Start software and wait for service initialization to complete

### 2. Device Connection

1. Device automatically connects to software after power on
2. Observe device status shows "Online"
3. Confirm data transmission status is normal

### 3. Basic Data Acquisition

1. Enable data stream in "Data Stream Control"
2. Select appropriate data stream mode and interval
3. Observe spectral curves in "Real-time Data" tab

### 4. Timed Measurement

1. Enable function in "Timed Measurement Control"
2. Set total measurement duration and interval
3. Click "Immediate Measurement" or wait for automatic measurement
4. View measurement results in respective tabs

### 5. Data Recording and Saving

1. Click "Start Recording" to begin data collection
2. Click "Stop Recording" after collection completes
3. Use "Save Recording" to export data as CSV file

---

## Advanced Features

### Measurement Sequence Description

Each measurement includes three phases:

1. **LED Only**: Only AS7341 LED turned on, collect 5 data points
2. **UV Only**: Only UV LED turned on, collect 5 data points
3. **LED+UV**: Both LEDs turned on simultaneously, collect 5 data points

### Data File Format

Saved CSV files contain the following fields:

- measurement_index: Measurement sequence number
- measurement_time: Measurement time
- measurement_type: Measurement type (LED Only/UV Only/LED+UV)
- data_index: Data point sequence number
- F1-F8: Spectral intensity values for 8 channels

---

## Troubleshooting

### Common Issues

1. **Device Cannot Connect**
   
   - Check if IP address settings are correct
   - Confirm device and computer are on the same network
   - Check firewall settings

2. **Data Reception Interruption**
   
   - Check network connection stability
   - Confirm UDP port 6699 is not occupied
   - Restart software and device

3. **Command Transmission Failure**
   
   - Check TCP client connection status
   - Confirm device command server is running normally
   - View command response prompts

4. **Abnormal Measurement Data**
   
   - Check LED status settings
   - Confirm device sensor is working properly
   - Check ambient lighting conditions

---

## Important Notes

1. Ensure device firmware version (v2.0.0) is compatible with software
2. Do not set data stream interval too small to avoid data loss
3. Maintain device stability during timed measurements
4. Regularly save important data to prevent accidental loss
5. Stop all data streams and measurements before closing software

---

## Technical Support

If encountering problems, please provide the following information:

1. Software version number
2. Device model and firmware version
3. Error message information
4. Network environment description
5. Problem reproduction steps

---

**Note**: This software is for professional use only. Please comply with relevant safety regulations when using. Commercial use is prohibited without author's permission (Author Teng email: tenwonyun@gmail.com).

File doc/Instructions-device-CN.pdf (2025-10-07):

# AS7341光谱仪设备使用说明书

# 1. 产品概述

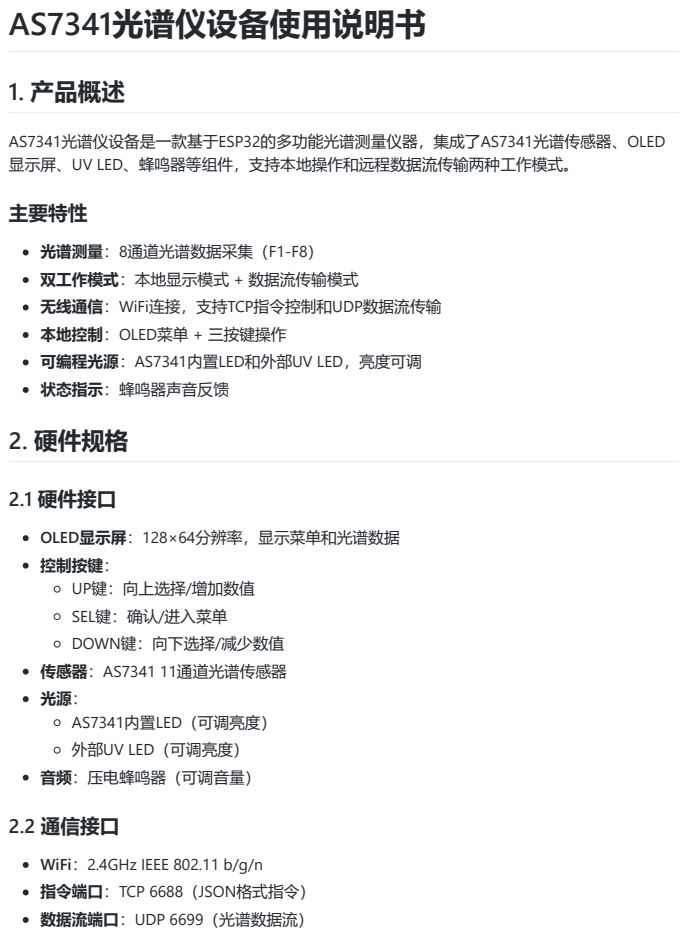
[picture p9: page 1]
2.1 硬件接口

AS7341光谱仪设备是一款基于ESP32的多功能光谱测量仪器，集成了AS7341光谱传感器、OLED
显示屏、UV LED、蜂鸣器等组件，支持本地操作和远程数据流传输两种工作模式。
主要特性

光谱测量：8通道光谱数据采集（F1-F8）
双工作模式：本地显示模式 + 数据流传输模式
无线通信：WiFi连接，支持TCP指令控制和UDP数据流传输
本地控制：OLED菜单 + 三按键操作
可编程光源：AS7341内置LED和外部UV LED，亮度可调
状态指示：蜂鸣器声音反馈
2. 硬件规格

OLED显示屏：128×64分辨率，显示菜单和光谱数据
控制按键：
UP键：向上选择/增加数值
SEL键：确认/进入菜单
DOWN键：向下选择/减少数值
传感器：AS7341 11通道光谱传感器
AS7341内置LED（可调亮度）
外部UV LED（可调亮度）
音频：压电蜂鸣器（可调音量）
2.2 通信接口

WiFi：2.4GHz IEEE 802.11 b/g/n
指令端口：TCP 6688（JSON格式指令）
数据流端口：UDP 6699（光谱数据流）

## 目标服务器端口：TCP 6677（状态通知） USB串口：波特率 115200 （开发调试）

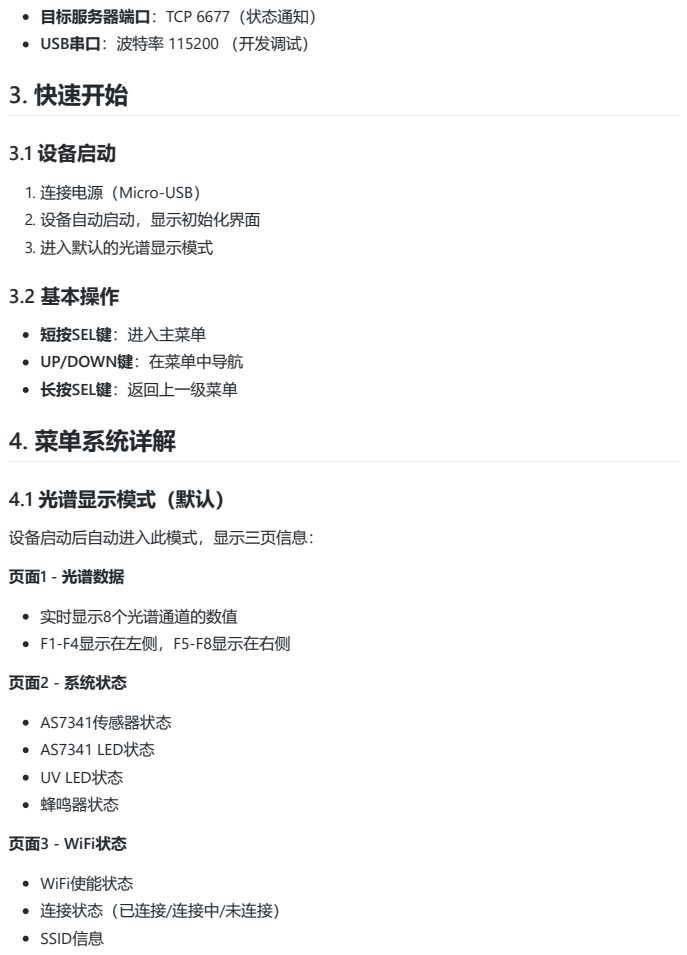
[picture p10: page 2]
3. 快速开始; 3.1 设备启动; 4.1 光谱显示模式（默认）; 设备启动后自动进入此模式，显示三页信息：; 页面1 - 光谱数据; 实时显示8个光谱通道的数值 F1-F4显示在左侧，F5-F8显示在右侧; 页面2 - 系统状态; AS7341传感器状态 AS7341 LED状态 UV LED状态 蜂鸣器状态; 页面3 - WiFi状态; WiFi使能状态 连接状态（已连接/连接中/未连接） SSID信息

1. 连接电源（Micro-USB）
2. 设备自动启动，显示初始化界面
3. 进入默认的光谱显示模式
3.2 基本操作

短按SEL键：进入主菜单
UP/DOWN键：在菜单中导航
长按SEL键：返回上一级菜单
4. 菜单系统详解

### IP地址信息 重连状态

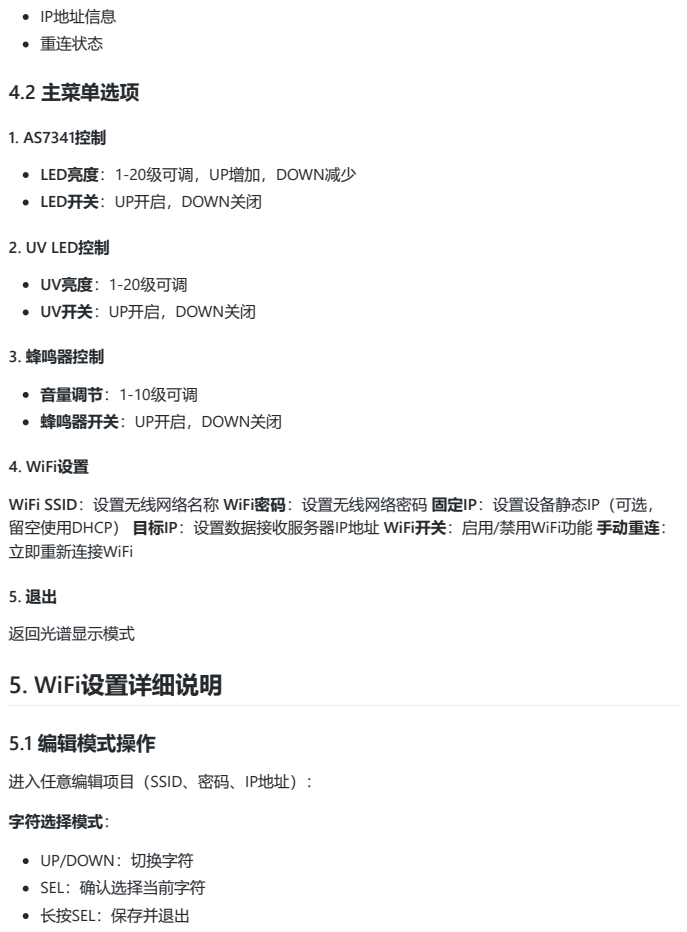
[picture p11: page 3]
4.2 主菜单选项; 返回光谱显示模式 5. WiFi设置详细说明; 5.1 编辑模式操作

LED亮度：1-20级可调，UP增加，DOWN减少
LED开关：UP开启，DOWN关闭

2. UV LED控制
UV亮度：1-20级可调
UV开关：UP开启，DOWN关闭

3. 蜂鸣器控制
音量调节：1-10级可调
蜂鸣器开关：UP开启，DOWN关闭

4. WiFi设置
WiFi SSID：设置无线网络名称 WiFi密码：设置无线网络密码 固定IP：设置设备静态IP（可选，
留空使用DHCP） 目标IP：设置数据接收服务器IP地址 WiFi开关：启用/禁用WiFi功能 手动重连：
立即重新连接WiFi

进入任意编辑项目（SSID、密码、IP地址）：
字符选择模式：
UP/DOWN：切换字符
SEL：确认选择当前字符
长按SEL：保存并退出

### 编辑模式（长按UP进入）：

### UP：光标右移

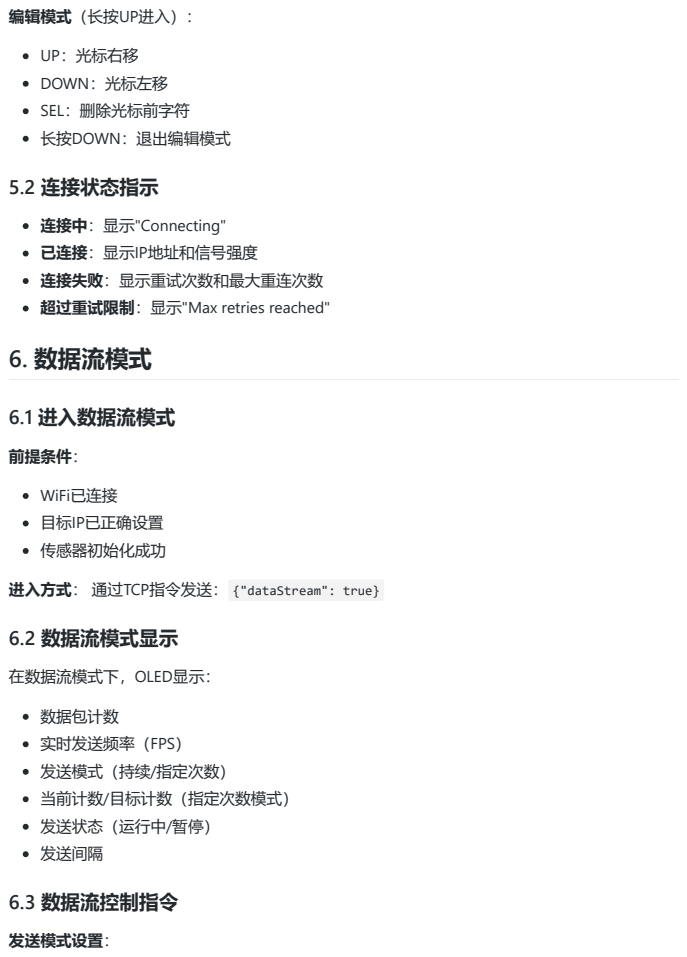
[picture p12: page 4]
DOWN：光标左移 SEL：删除光标前字符 长按DOWN：退出编辑模式; 5.2 连接状态指示; 6.1 进入数据流模式; 前提条件：; WiFi已连接 目标IP已正确设置 传感器初始化成功; 在数据流模式下，OLED显示：; 发送模式设置：

连接中：显示"Connecting"
已连接：显示IP地址和信号强度
连接失败：显示重试次数和最大重连次数
超过重试限制：显示"Max retries reached"
6. 数据流模式

进入方式： 通过TCP指令发送： {"dataStream": true}
6.2 数据流模式显示

数据包计数
实时发送频率（FPS）
发送模式（持续/指定次数）
当前计数/目标计数（指定次数模式）
发送状态（运行中/暂停）
发送间隔
6.3 数据流控制指令

## 单独设置发送次数：

{"streamCount": 500}

## 退出数据流模式：

{"dataStream": false}

# 7. 远程控制指令

## 7.1 设备控制指令

## AS7341 LED控制：

## UV LED控制：

## 蜂鸣器控制：

## 设备状态查询：

{"getDeviceStatus": true}

## 设备重启：

{"reboot": true}

## 7.2 指令响应

### 设备对每个指令都会返回JSON格式响应：

# 8. 数据格式说明

## 8.1 光谱数据格式（UDP）

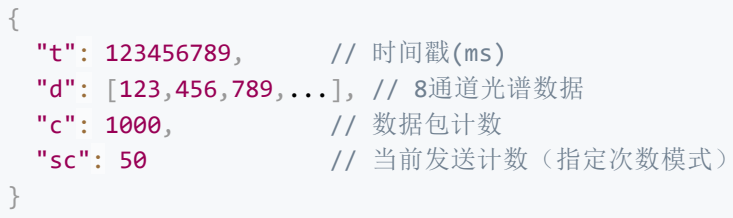
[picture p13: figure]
// 时间戳(ms); [123,456,789,...], // 8通道光谱数据; // 数据包计数; // 当前发送计数（指定次数模式）

## 8.2 设备状态格式

{
"type": | "deviceStatus",
"device": | "AS7341_Sensor_Device",
"timestamp": | 123456789,
"status": | {
"as7341_led": | true,
"as7341_bright": | 10,
"uv_led": | false,
"uv_bright": | 15,
"buzzer": | true,
"sensor": | true,
"stream_mode": | "continuous",
"stream_paused": | false,
"packet_count": | 1000,
"interval": | 100,
"current_count": | 500,
"target_count": | 1000
}
}

## 8.3 连接状态通知

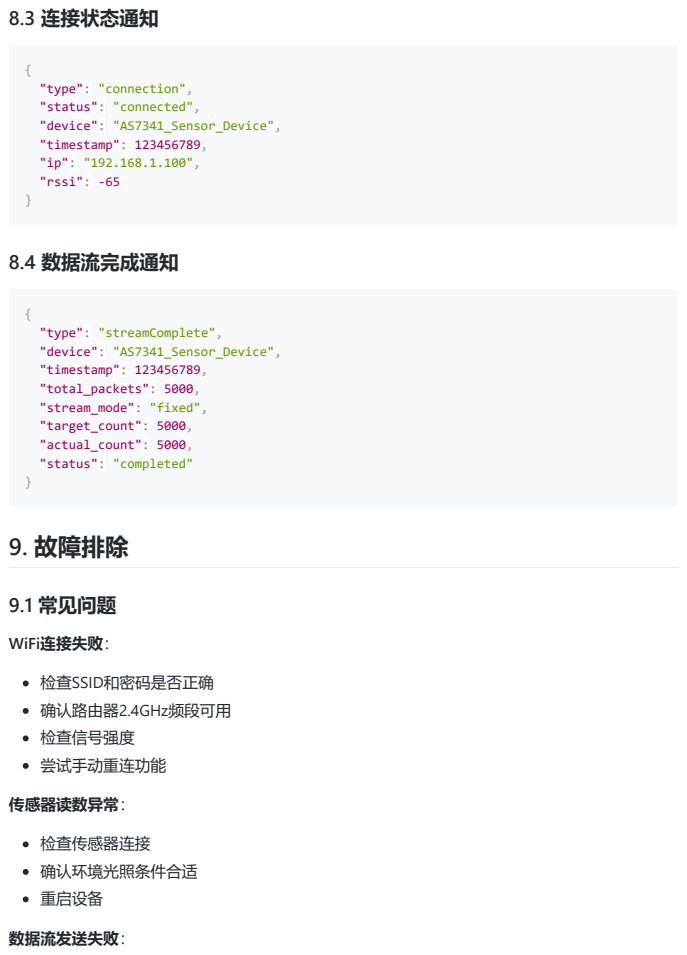
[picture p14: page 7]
"type":; "connection",; "status":; "connected",; "device":; "AS7341_Sensor_Device",; "timestamp":; "rssi":; 8.4 数据流完成通知; "streamComplete",; "total_packets":; "stream_mode":; "fixed",; "target_count":; "actual_count":; "completed"; 9. 故障排除; 9.1 常见问题; WiFi连接失败：; 检查SSID和密码是否正确 确认路由器2.4GHz频段可用 检查信号强度 尝试手动重连功能; 传感器读数异常：; 检查传感器连接 确认环境光照条件合适 重启设备; 数据流发送失败：

### 确认目标IP和端口正确 检查网络连通性

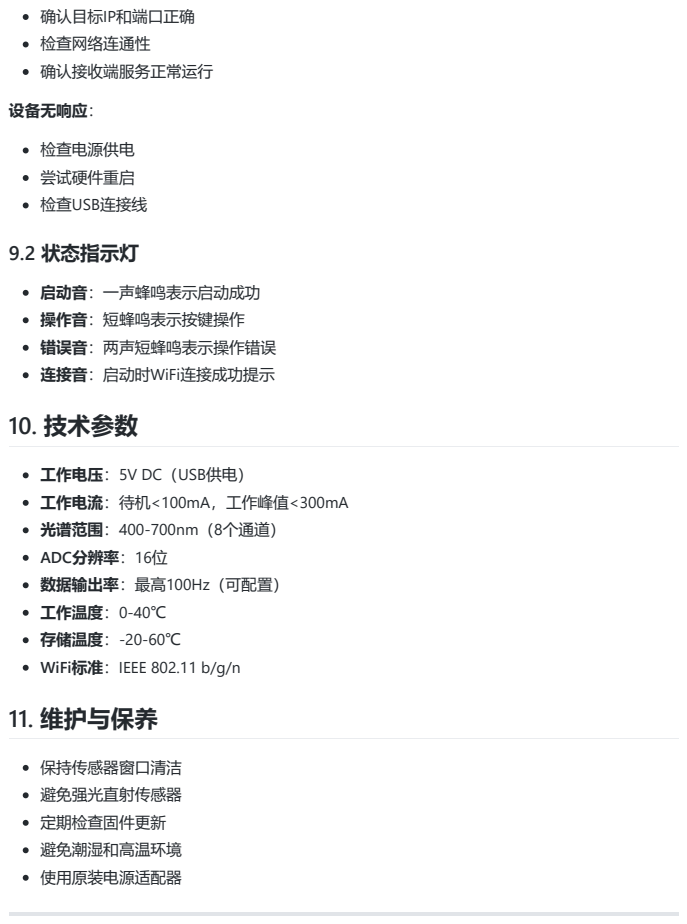
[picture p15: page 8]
确认接收端服务正常运行; 设备无响应：; 检查电源供电 尝试硬件重启 检查USB连接线; 9.2 状态指示灯; 启动音：一声蜂鸣表示启动成功 操作音：短蜂鸣表示按键操作 错误音：两声短蜂鸣表示操作错误 连接音：启动时WiFi连接成功提示 10. 技术参数; 保持传感器窗口清洁 避免强光直射传感器 定期检查固件更新 避免潮湿和高温环境 使用原装电源适配器

工作电压：5V DC（USB供电）
工作电流：待机<100mA，工作峰值<300mA
光谱范围：400-700nm（8个通道）
ADC分辨率：16位
数据输出率：最高100Hz（可配置）
工作温度：0-40℃
存储温度：-20-60℃
WiFi标准：IEEE 802.11 b/g/n
11. 维护与保养

### 技术支持：如遇问题，请记录设备显示的异常信息并联系技术支持人员（Teng

## email:tenwonyun@gmail.com）。

### 版本信息：本说明书对应固件版本 v2.0.0

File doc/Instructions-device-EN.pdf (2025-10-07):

# AS7341 Spectrometer Device User Manual

## 1. Product Overview

The AS7341 Spectrometer Device is a multi-functional spectral measurement instrument based on ESP32, integrating AS7341 spectral sensor, OLED display, UV LED, buzzer and other components. It supports two operation modes: local operation and remote data stream transmission.

### Key Features

Spectral Measurement: 8-channel spectral data acquisition (F1-F8)
Dual Operation Modes: Local display mode + Data stream transmission mode Wireless Communication: WiFi connectivity, supporting TCP command control and UDP data stream transmission
Local Control: OLED menu + Three-button operation
Programmable Light Sources: AS7341 built-in LED and external UV LED with adjustable brightness
Status Indication: Buzzer audio feedback

## 2. Hardware Specifications

### 2.1 Hardware Interfaces

OLED Display: 128×64 resolution, displaying menu and spectral data Control Buttons:
UP Button: Navigate up/Increase value
SEL Button: Confirm/Enter menu
DOWN Button: Navigate down/Decrease value Sensor: AS7341 11-channel spectral sensor
Light Sources:
AS7341 built-in LED (adjustable brightness) External UV LED (adjustable brightness) Audio: Piezo buzzer (adjustable volume)

### 2.2 Communication Interfaces

## 3. Quick Start

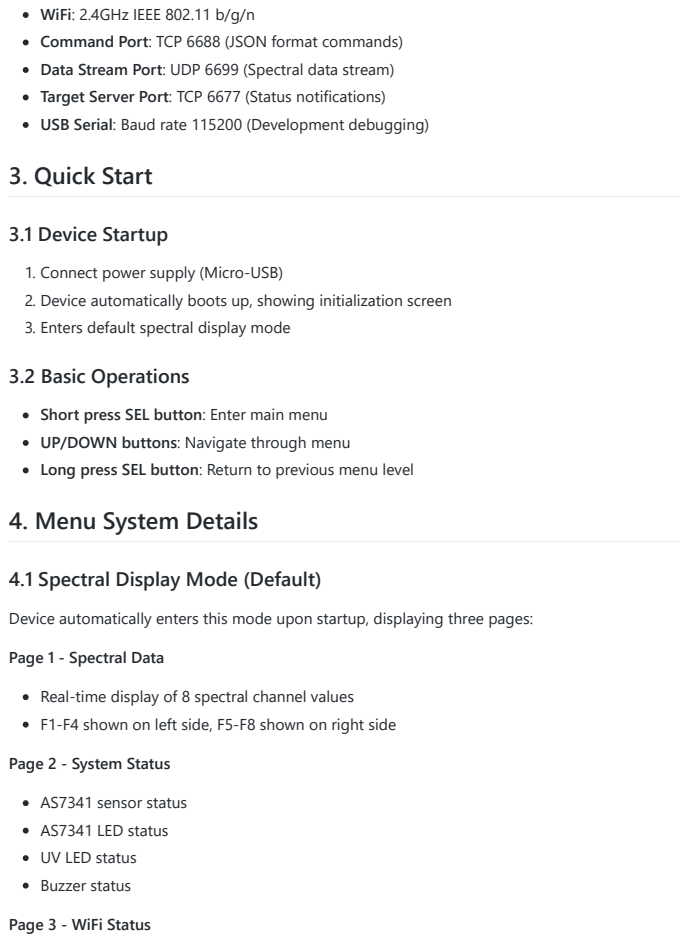
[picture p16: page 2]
3.1 Device Startup

WiFi: 2.4GHz IEEE 802.11 b/g/n
Command Port: TCP 6688 (JSON format commands)
Data Stream Port: UDP 6699 (Spectral data stream)
Target Server Port: TCP 6677 (Status notifications)
USB Serial: Baud rate 115200 (Development debugging)

1. Connect power supply (Micro-USB)
2. Device automatically boots up, showing initialization screen
3. Enters default spectral display mode
3.2 Basic Operations

Short press SEL button: Enter main menu
UP/DOWN buttons: Navigate through menu
Long press SEL button: Return to previous menu level
4. Menu System Details

4.1 Spectral Display Mode (Default)

Device automatically enters this mode upon startup, displaying three pages:
Page 1 - Spectral Data
Real-time display of 8 spectral channel values
F1-F4 shown on left side, F5-F8 shown on right side
Page 2 - System Status
AS7341 sensor status
AS7341 LED status
UV LED status
Buzzer status
Page 3 - WiFi Status

WiFi enable status
Connection status (Connected/Connecting/Not connected) SSID information
IP address information
Reconnection status

### 4.2 Main Menu Options

### 1. AS7341 Control

LED Brightness: 1-20 levels adjustable, UP increases, DOWN decreases LED Switch: UP turns on, DOWN turns off

### 2. UV LED Control

UV Brightness: 1-20 levels adjustable
UV Switch: UP turns on, DOWN turns off

### 3. Buzzer Control

Volume Adjustment: 1-10 levels adjustable Buzzer Switch: UP turns on, DOWN turns off

### 4. WiFi Settings

WiFi SSID: Set wireless network name WiFi Password: Set wireless network password Static IP: Set device static IP (Optional, leave blank for DHCP) Target IP: Set data receiving server IP address WiFi Switch: Enable/disable WiFi function Manual Reconnect: Immediately reconnect to WiFi

### 5. Exit

Return to spectral display mode

## 5. WiFi Settings Detailed Instructions

### 5.1 Edit Mode Operations

Enter any editing item (SSID, password, IP address):

Character Selection Mode:

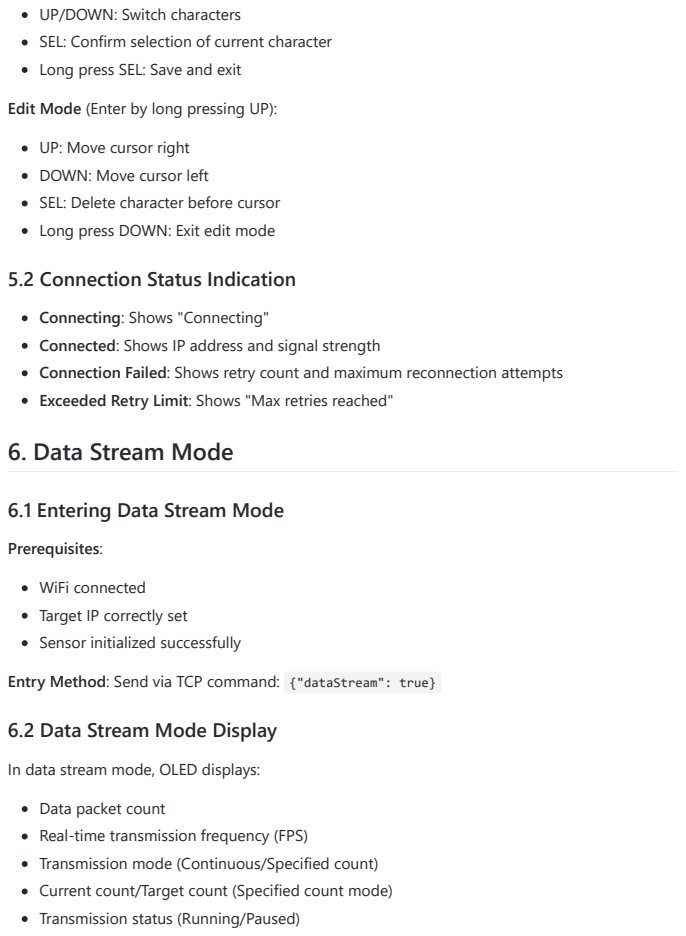
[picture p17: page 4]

UP/DOWN: Switch characters
SEL: Confirm selection of current character
Long press SEL: Save and exit
Edit Mode (Enter by long pressing UP):
UP: Move cursor right
DOWN: Move cursor left
SEL: Delete character before cursor
Long press DOWN: Exit edit mode
5.2 Connection Status Indication

Connecting: Shows "Connecting"
Connected: Shows IP address and signal strength
Connection Failed: Shows retry count and maximum reconnection attempts
Exceeded Retry Limit: Shows "Max retries reached"
6. Data Stream Mode

6.1 Entering Data Stream Mode

Prerequisites:
WiFi connected
Target IP correctly set
Sensor initialized successfully
Entry Method: Send via TCP command: {"dataStream": true}
6.2 Data Stream Mode Display

In data stream mode, OLED displays:
Data packet count
Real-time transmission frequency (FPS)
Transmission mode (Continuous/Specified count)
Current count/Target count (Specified count mode)
Transmission status (Running/Paused)

Transmission interval

### 6.3 Data Stream Control Commands

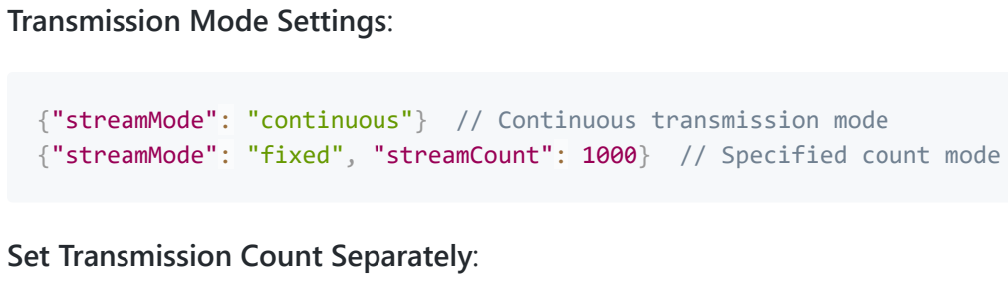
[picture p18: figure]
Transmission Mode Settings:; {"streamMode":; "continuous"} // Continuous transmission mode; "fixed", "streamCount":; 1000} // Specified count mode; Set Transmission Count Separately:

{"streamCount": 500}

Exit Data Stream Mode:

{"dataStream": false}

## 7. Remote Control Commands

### 7.1 Device Control Commands

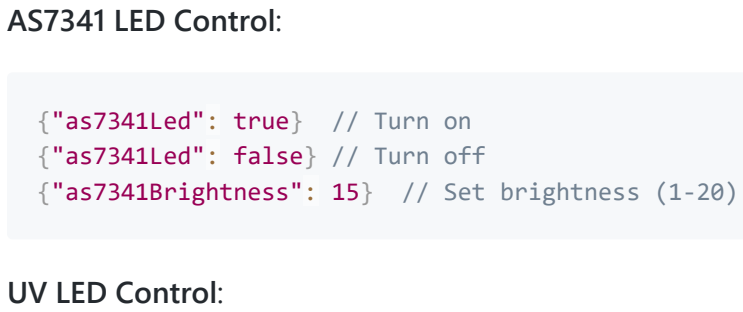
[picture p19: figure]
AS7341 LED Control:; {"as7341Led":; true} // Turn on; false} // Turn off; {"as7341Brightness":; 15} // Set brightness (1-20); UV LED Control:
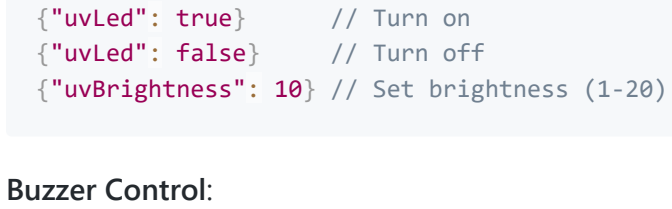
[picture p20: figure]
{"uvLed":; true}; // Turn on; false}; // Turn off; {"uvBrightness":; 10} // Set brightness (1-20); Buzzer Control:

Device Status Query:

{"getDeviceStatus": true}

Device Reboot:

{"reboot": true}

### 7.2 Command Responses

Device returns JSON format response for each command:

## 8. Data Format Specifications

### 8.1 Spectral Data Format (UDP)

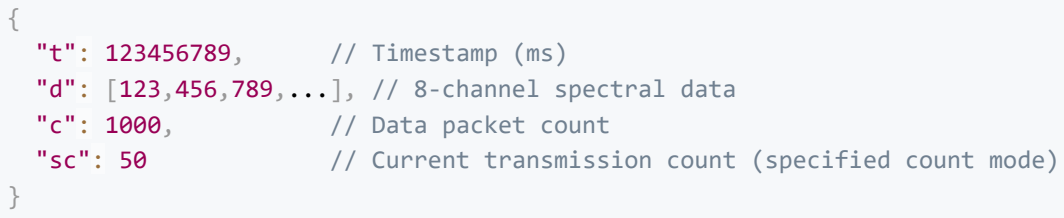
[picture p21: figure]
// Timestamp (ms); [123,456,789,...], // 8-channel spectral data; // Data packet count

"sc": | 50 | // Current transmission count (specified count mode)

### 8.2 Device Status Format

{
"type": | "deviceStatus",
"device": | "AS7341_Sensor_Device",
"timestamp": | 123456789,
"status": | {
"as7341_led": | true,
"as7341_bright": | 10,
"uv_led": | false,
"uv_bright": | 15,
"buzzer": | true,
"sensor": | true,
"stream_mode": | "continuous",
"stream_paused": | false,
"packet_count": | 1000,
"interval": | 100,
"current_count": | 500,
"target_count": | 1000
}
}

### 8.3 Connection Status Notification

{
"type": | "connection",
"status": | "connected",
"device": | "AS7341_Sensor_Device",
"timestamp": | 123456789,
"ip": | "192.168.1.100",
"rssi": | -65
}

### 8.4 Data Stream Completion Notification

{
"type": | "streamComplete",
"device": | "AS7341_Sensor_Device",
"timestamp": | 123456789,
"total_packets": | 5000,
"stream_mode": | "fixed",
"target_count": | 5000,
"actual_count": | 5000,
"status": | "completed"
}

## 9. Troubleshooting

### 9.1 Common Issues

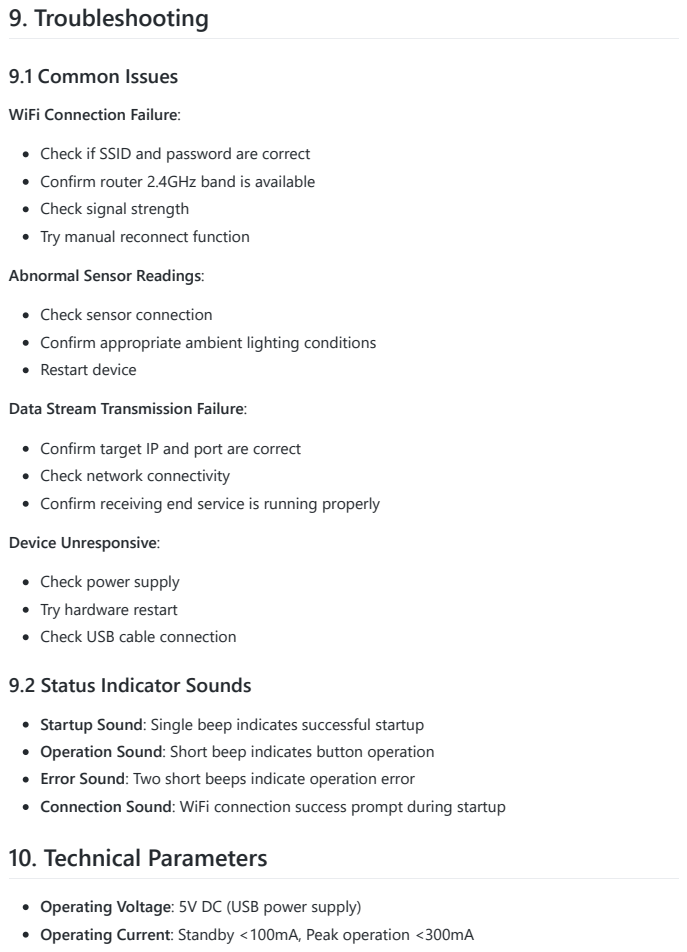
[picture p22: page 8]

WiFi Connection Failure:
Check if SSID and password are correct
Confirm router 2.4GHz band is available
Check signal strength
Try manual reconnect function
Abnormal Sensor Readings:
Check sensor connection
Confirm appropriate ambient lighting conditions
Restart device
Data Stream Transmission Failure:
Confirm target IP and port are correct
Check network connectivity
Confirm receiving end service is running properly
Device Unresponsive:
Check power supply
Try hardware restart
Check USB cable connection
9.2 Status Indicator Sounds

Startup Sound: Single beep indicates successful startup
Operation Sound: Short beep indicates button operation
Error Sound: Two short beeps indicate operation error
Connection Sound: WiFi connection success prompt during startup
10. Technical Parameters

Operating Voltage: 5V DC (USB power supply)
Operating Current: Standby <100mA, Peak operation <300mA

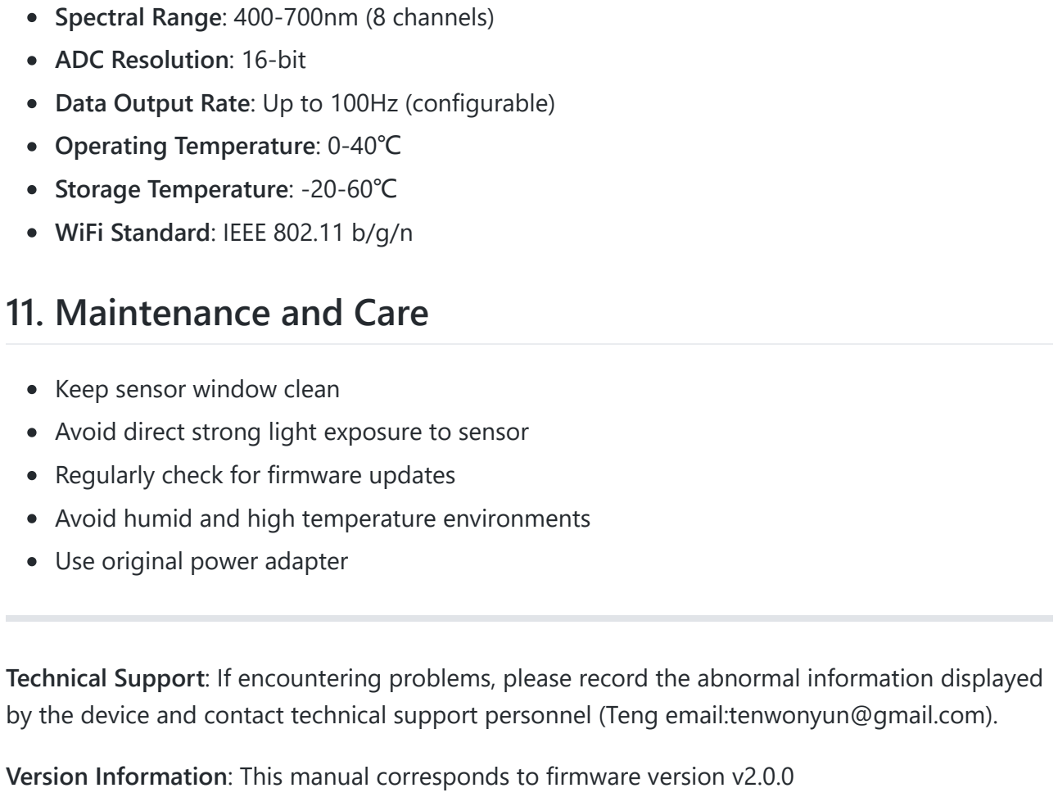
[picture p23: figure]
Spectral Range: 400-700nm (8 channels) ADC Resolution: 16-bit; Operating Temperature: 0-40℃ Storage Temperature: -20-60℃ WiFi Standard: IEEE 802.11 b/g/n 11. Maintenance and Care; Keep sensor window clean; Regularly check for firmware updates; Use original power adapter

Data Output Rate: Up to 100Hz (configurable)

Avoid direct strong light exposure to sensor

Avoid humid and high temperature environments

Technical Support: If encountering problems, please record the abnormal information displayed by the device and contact technical support personnel (Teng email:tenwonyun@gmail.com).

Version Information: This manual corresponds to firmware version v2.0.0

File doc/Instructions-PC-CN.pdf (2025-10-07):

# 光谱仪上位机软件使用说明书

## 软件概述

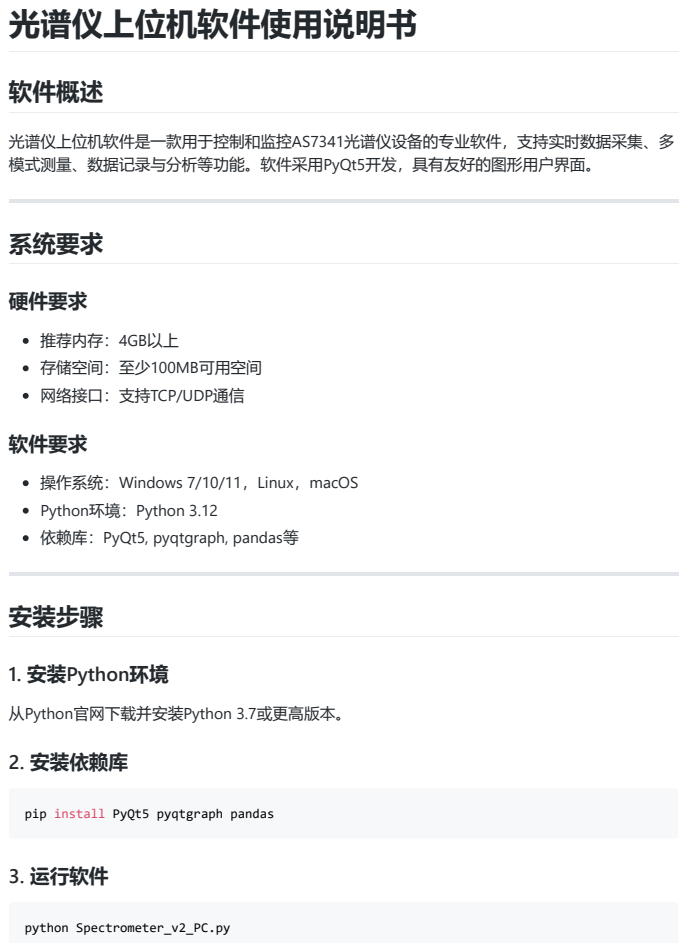
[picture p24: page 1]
系统要求; 硬件要求; 安装步骤; 1. 安装Python环境; 从Python官网下载并安装Python 3.7或更高版本。; 2. 安装依赖库; 3. 运行软件; python Spectrometer_v2_PC.py

光谱仪上位机软件是一款用于控制和监控AS7341光谱仪设备的专业软件，支持实时数据采集、多
模式测量、数据记录与分析等功能。软件采用PyQt5开发，具有友好的图形用户界面。

推荐内存：4GB以上
存储空间：至少100MB可用空间
网络接口：支持TCP/UDP通信
软件要求

操作系统：Windows 7/10/11，Linux，macOS
Python环境：Python 3.12
依赖库：PyQt5, pyqtgraph, pandas等

pip install PyQt5 pyqtgraph pandas

## 界面功能详解

### 1. 顶部状态栏

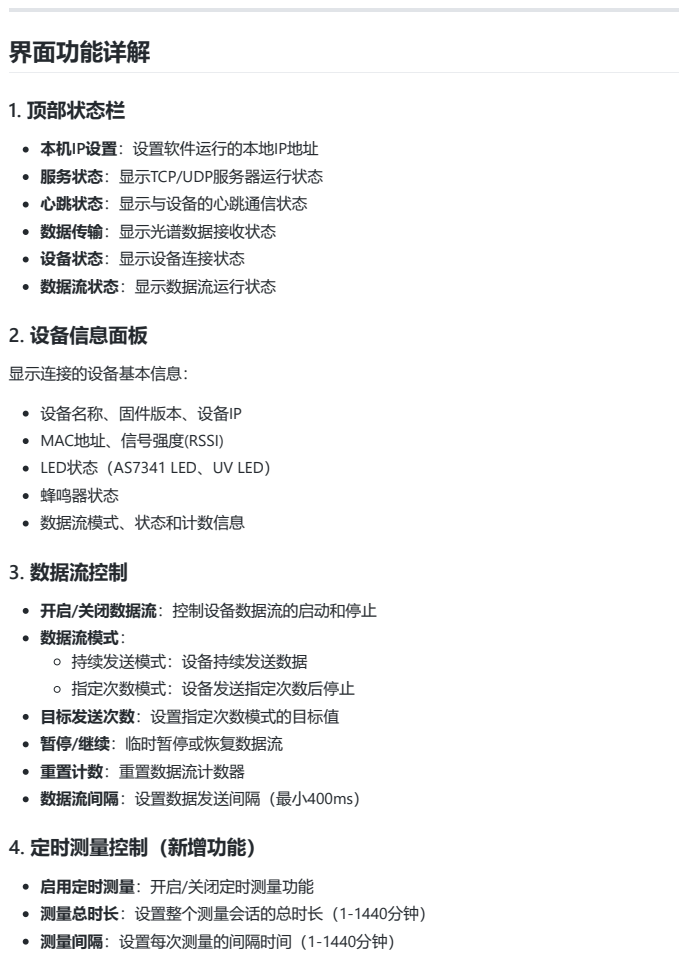
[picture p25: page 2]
显示连接的设备基本信息：

本机IP设置：设置软件运行的本地IP地址
服务状态：显示TCP/UDP服务器运行状态
心跳状态：显示与设备的心跳通信状态
数据传输：显示光谱数据接收状态
设备状态：显示设备连接状态
数据流状态：显示数据流运行状态
2. 设备信息面板

设备名称、固件版本、设备IP
MAC地址、信号强度(RSSI)
LED状态（AS7341 LED、UV LED）
蜂鸣器状态
数据流模式、状态和计数信息
3. 数据流控制

开启/关闭数据流：控制设备数据流的启动和停止
数据流模式：
持续发送模式：设备持续发送数据
指定次数模式：设备发送指定次数后停止
目标发送次数：设置指定次数模式的目标值
暂停/继续：临时暂停或恢复数据流
重置计数：重置数据流计数器
数据流间隔：设置数据发送间隔（最小400ms）
4. 定时测量控制（新增功能）

启用定时测量：开启/关闭定时测量功能
测量总时长：设置整个测量会话的总时长（1-1440分钟）
测量间隔：设置每次测量的间隔时间（1-1440分钟）

### 5. 设备参数控制

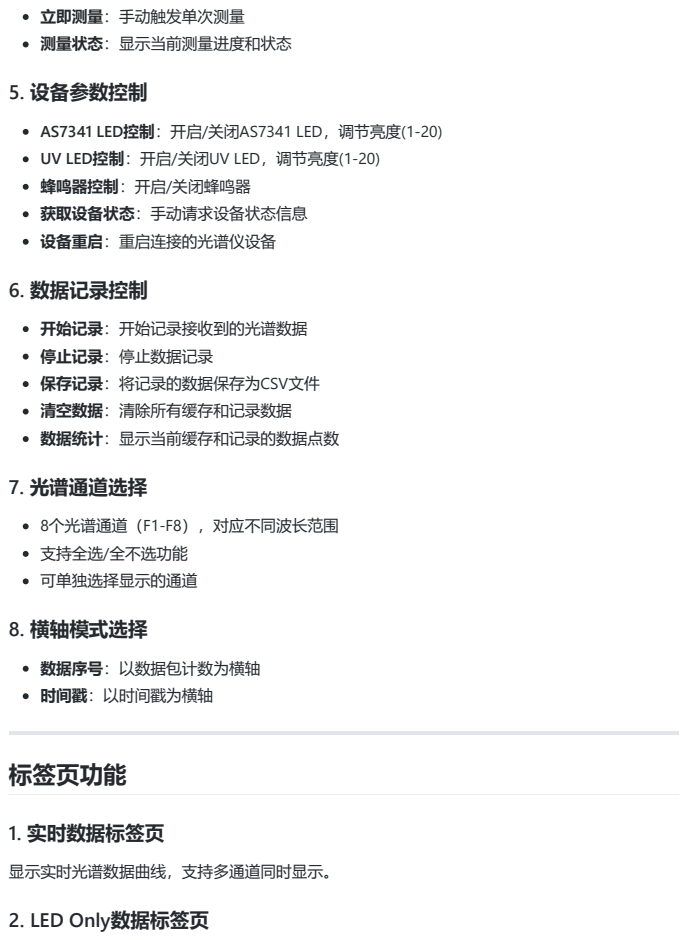
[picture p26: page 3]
立即测量：手动触发单次测量 测量状态：显示当前测量进度和状态; 开始记录：开始记录接收到的光谱数据 停止记录：停止数据记录 保存记录：将记录的数据保存为CSV文件 清空数据：清除所有缓存和记录数据 数据统计：显示当前缓存和记录的数据点数; 7. 光谱通道选择; 8个光谱通道（F1-F8），对应不同波长范围 支持全选/全不选功能 可单独选择显示的通道; 8. 横轴模式选择; 数据序号：以数据包计数为横轴 时间戳：以时间戳为横轴; 标签页功能; 1. 实时数据标签页; 显示实时光谱数据曲线，支持多通道同时显示。; 2. LED Only数据标签页

AS7341 LED控制：开启/关闭AS7341 LED，调节亮度(1-20)
UV LED控制：开启/关闭UV LED，调节亮度(1-20)
蜂鸣器控制：开启/关闭蜂鸣器
获取设备状态：手动请求设备状态信息
设备重启：重启连接的光谱仪设备
6. 数据记录控制

显示仅开启LED时的测量数据平均值。

### 3. UV Only数据标签页

显示仅开启UV灯时的测量数据平均值。

### 4. LED+UV数据标签页

显示同时开启LED和UV灯时的测量数据平均值。

## 使用流程

### 1. 初始设置

1. 确认本机IP地址设置正确
2. 确保设备与电脑在同一网络
3. 启动软件，等待服务初始化完成

### 2. 设备连接

1. 设备开机后自动连接软件
2. 观察设备状态显示"在线"
3. 确认数据传输状态正常

### 3. 基本数据采集

1. 在"数据流控制"中开启数据流
2. 选择合适的数据流模式和间隔
3. 在"实时数据"标签页观察光谱曲线

### 4. 定时测量

1. 在"定时测量控制"中启用功能
2. 设置测量总时长和间隔
3. 点击"立即测量"或等待自动测量
4. 在各标签页查看测量结果

### 5. 数据记录与保存

## 高级功能

### 测量序列说明

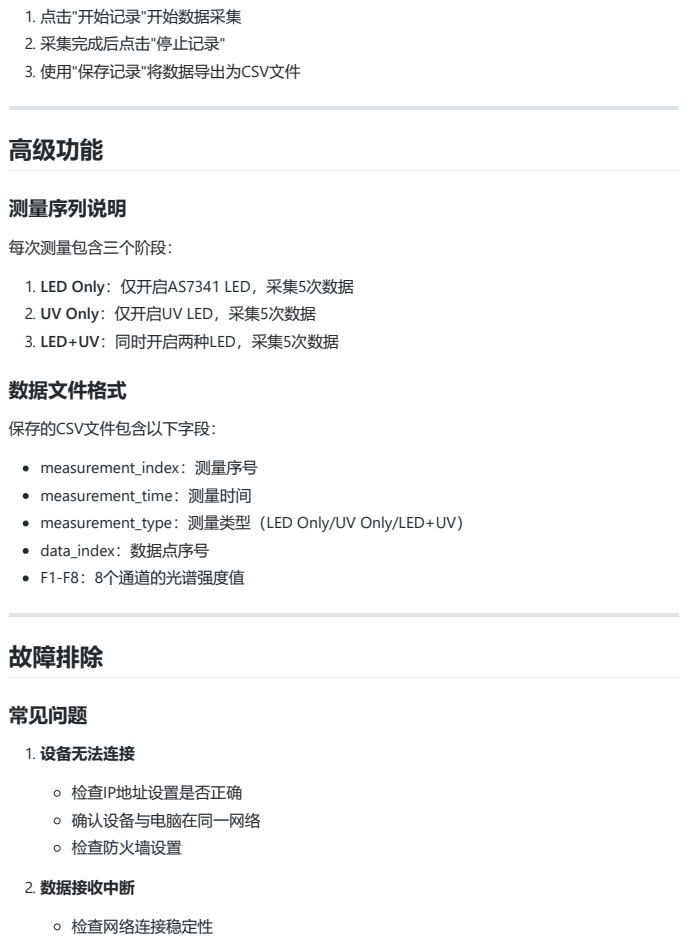
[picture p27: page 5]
故障排除; 常见问题; 1. 设备无法连接; 检查IP地址设置是否正确 确认设备与电脑在同一网络 检查防火墙设置; 2. 数据接收中断; 检查网络连接稳定性

1. 点击"开始记录"开始数据采集
2. 采集完成后点击"停止记录"
3. 使用"保存记录"将数据导出为CSV文件

每次测量包含三个阶段：
1. LED Only：仅开启AS7341 LED，采集5次数据
2. UV Only：仅开启UV LED，采集5次数据
3. LED+UV：同时开启两种LED，采集5次数据
数据文件格式

保存的CSV文件包含以下字段：
measurement_index：测量序号
measurement_time：测量时间
measurement_type：测量类型（LED Only/UV Only/LED+UV）
data_index：数据点序号
F1-F8：8个通道的光谱强度值

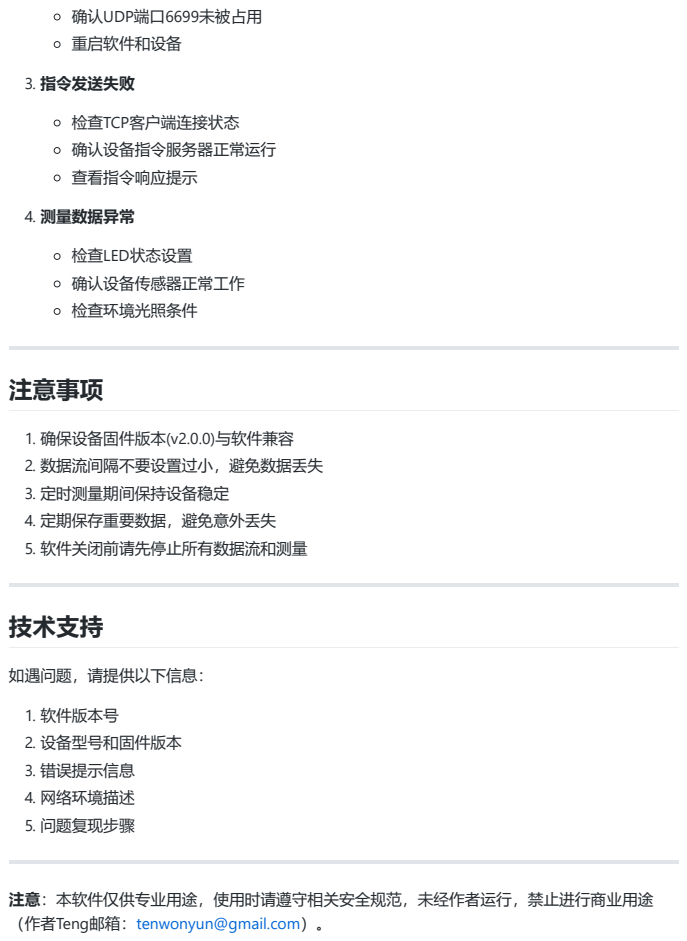
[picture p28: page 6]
确认UDP端口6699未被占用 重启软件和设备; 3. 指令发送失败; 检查TCP客户端连接状态 确认设备指令服务器正常运行 查看指令响应提示; 4. 测量数据异常; 检查LED状态设置 确认设备传感器正常工作 检查环境光照条件; 注意事项; 1. 确保设备固件版本(v2.0.0)与软件兼容 2. 数据流间隔不要设置过小，避免数据丢失 3. 定时测量期间保持设备稳定 4. 定期保存重要数据，避免意外丢失 5. 软件关闭前请先停止所有数据流和测量; 技术支持; 如遇问题，请提供以下信息：; 1. 软件版本号 2. 设备型号和固件版本 3. 错误提示信息 4. 网络环境描述 5. 问题复现步骤

注意：本软件仅供专业用途，使用时请遵守相关安全规范，未经作者运行，禁止进行商业用途
（作者Teng邮箱：tenwonyun@gmail.com）。

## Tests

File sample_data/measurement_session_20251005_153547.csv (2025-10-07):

measurement_index | measurement_time | measurement_type | data_index | F1 | F2 | F3 | F4 | F5 | F6 | F7 | F8
0 | 2025-10-05 15:37:07 | LED Only | 0 | 32 | 40 | 30 | 23 | 15 | 14 | 15 | 9
0 | 2025-10-05 15:37:07 | LED Only | 1 | 32 | 40 | 30 | 24 | 15 | 14 | 16 | 9
0 | 2025-10-05 15:37:07 | LED Only | 2 | 31 | 41 | 30 | 24 | 15 | 14 | 15 | 9
0 | 2025-10-05 15:37:07 | LED Only | 3 | 37 | 90 | 56 | 76 | 103 | 102 | 87 | 50
0 | 2025-10-05 15:37:07 | LED Only | 4 | 7 | 51 | 27 | 54 | 87 | 88 | 71 | 41
0 | 2025-10-05 15:37:07 | UV Only | 0 | 7 | 51 | 28 | 53 | 87 | 88 | 72 | 41
0 | 2025-10-05 15:37:07 | UV Only | 1 | 7 | 51 | 28 | 53 | 87 | 88 | 72 | 41
0 | 2025-10-05 15:37:07 | UV Only | 2 | 0 | 0 | 0 | 0 | 0 | 0 | 0 | 0
0 | 2025-10-05 15:37:07 | UV Only | 3 | 0 | 0 | 0 | 0 | 0 | 0 | 0 | 0
0 | 2025-10-05 15:37:07 | UV Only | 4 | 0 | 0 | 0 | 0 | 0 | 0 | 0 | 0
0 | 2025-10-05 15:37:07 | LED+UV | 0 | 0 | 0 | 0 | 0 | 0 | 0 | 0 | 0
0 | 2025-10-05 15:37:07 | LED+UV | 1 | 31 | 40 | 30 | 23 | 15 | 14 | 14 | 8
0 | 2025-10-05 15:37:07 | LED+UV | 2 | 31 | 40 | 30 | 23 | 15 | 14 | 14 | 8
0 | 2025-10-05 15:37:07 | LED+UV | 3 | 31 | 40 | 30 | 23 | 15 | 14 | 14 | 8
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

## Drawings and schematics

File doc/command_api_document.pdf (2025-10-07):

# AS7341 Spectral Sensor Device Communication Protocol Documentation

## 1. Device Basic Information

Device Name: AS7341_Sensor_Device Device Type: Spectral_Sensor
Firmware Version: 2.0.0
Communication Protocol: TCP + UDP

## 2. Communication Port Configuration

Port | Protocol | Purpose | Direction
6677 | TCP | Target server connection, data stream control | Bidirectional
6688 | TCP | Command server, device control | Bidirectional
6699 | UDP | Data stream transmission | Device → Host

## 3. Command Format

All commands are in JSON format and sent via TCP port 6688.

### 3.1 Basic Command Structure

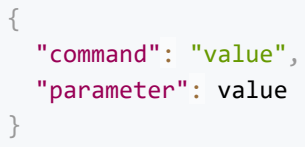
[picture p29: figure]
"command": "value", "parameter": value

## 4. Device Control Commands

### 4.1 Data Stream Mode Control

Enter Data Stream Mode

### 4.2 Data Stream Transmission Control

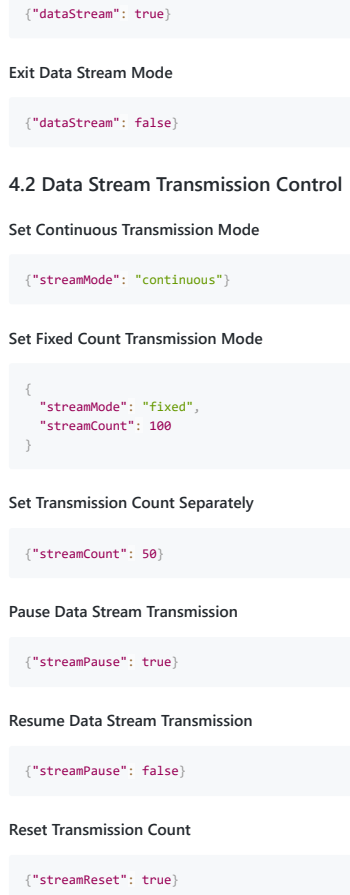
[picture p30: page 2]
{"dataStream":; true}; false}; {"streamMode":; "continuous"}; "streamMode":; "fixed",; "streamCount":; {"streamCount":; {"streamPause":; {"streamReset":

Exit Data Stream Mode

Set Continuous Transmission Mode

Set Fixed Count Transmission Mode

Set Transmission Count Separately

Pause Data Stream Transmission

Resume Data Stream Transmission

Reset Transmission Count

### 4.3 Device Hardware Control

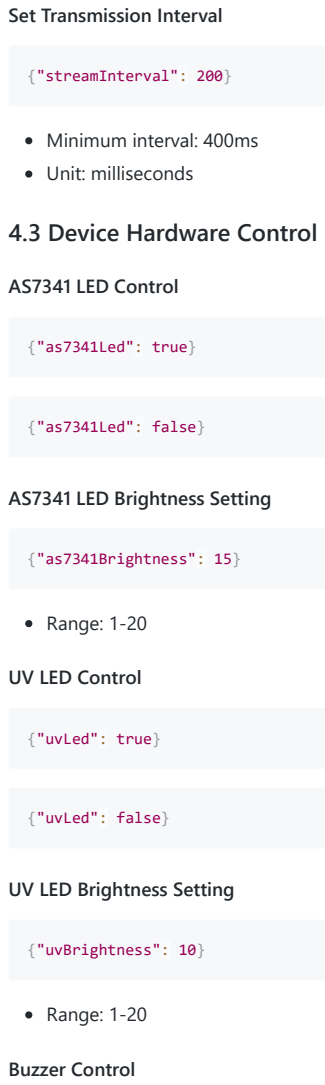
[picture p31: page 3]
{"streamInterval":; Minimum interval: 400ms Unit: milliseconds; AS7341 LED Control; {"as7341Led":; true}; false}; {"as7341Brightness":; Range: 1-20; {"uvLed":; {"uvBrightness":; Buzzer Control

Set Transmission Interval

AS7341 LED Brightness Setting

UV LED Control

UV LED Brightness Setting

### 4.4 System Commands

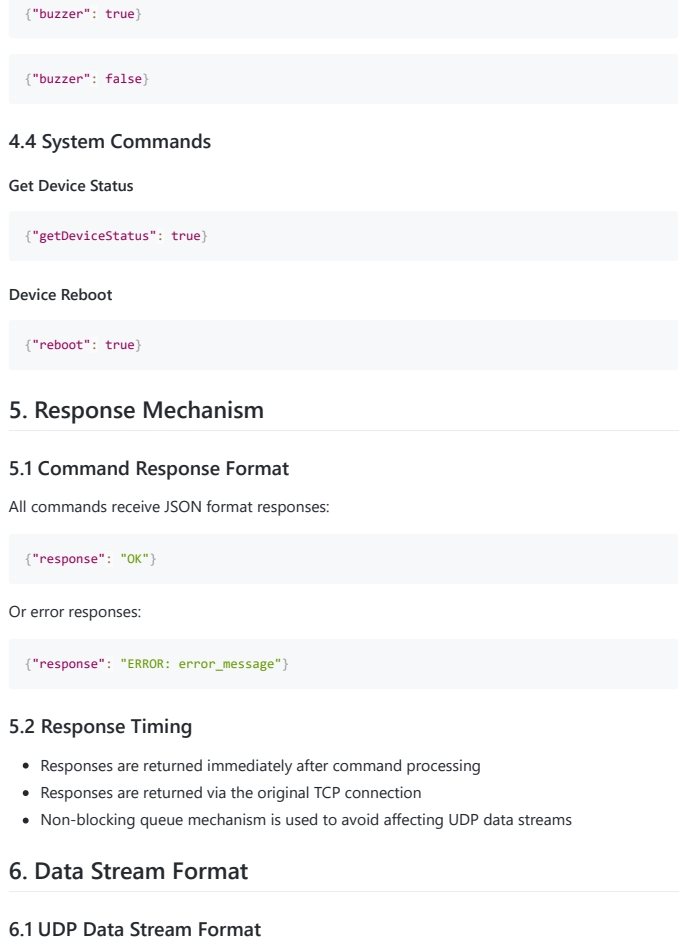
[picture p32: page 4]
{"buzzer":; true}; false}; {"getDeviceStatus":; Device Reboot; {"reboot":; 5. Response Mechanism; {"response":; "ERROR: error_message"}; 5.2 Response Timing

Get Device Status

5.1 Command Response Format

All commands receive JSON format responses:

Or error responses:

Responses are returned immediately after command processing
Responses are returned via the original TCP connection
Non-blocking queue mechanism is used to avoid affecting UDP data streams
6. Data Stream Format

6.1 UDP Data Stream Format

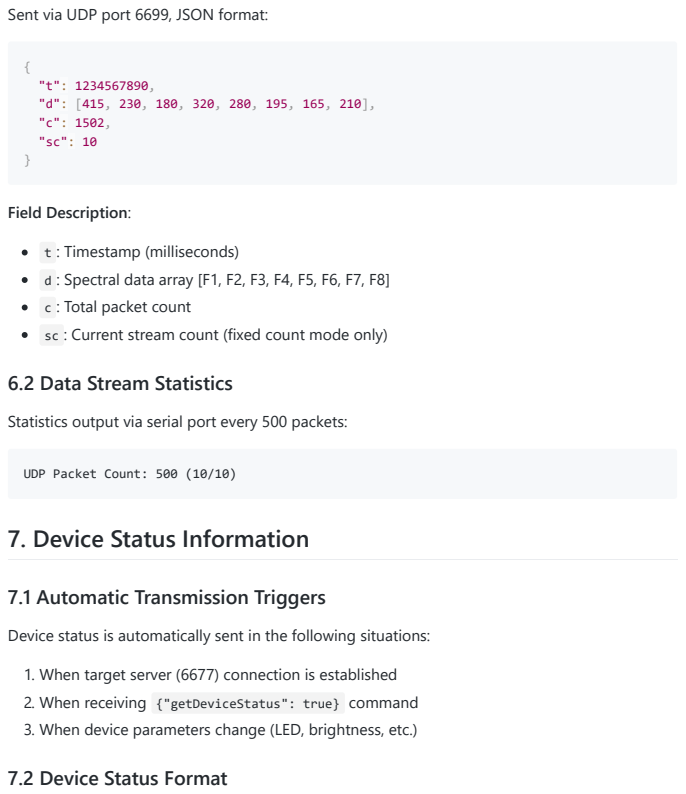
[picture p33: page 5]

Sent via UDP port 6699, JSON format:

Field Description:
t : Timestamp (milliseconds)
d : Spectral data array [F1, F2, F3, F4, F5, F6, F7, F8]
c : Total packet count
sc : Current stream count (fixed count mode only)
6.2 Data Stream Statistics

Statistics output via serial port every 500 packets:

UDP Packet Count: 500 (10/10)
7. Device Status Information

7.1 Automatic Transmission Triggers

Device status is automatically sent in the following situations:
1. When target server (6677) connection is established
2. When receiving {"getDeviceStatus": true} command
3. When device parameters change (LED, brightness, etc.)
7.2 Device Status Format

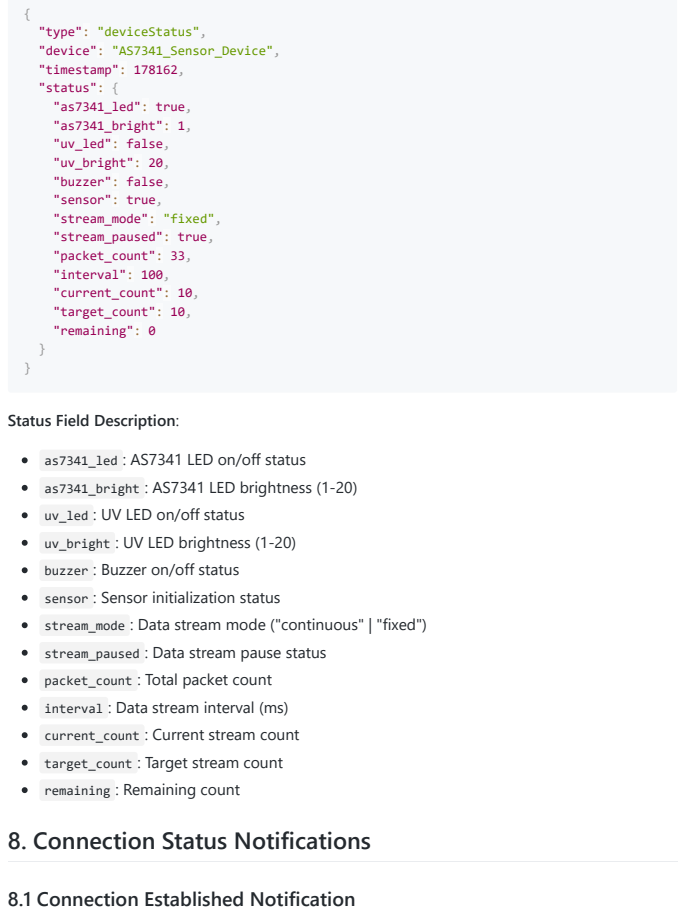
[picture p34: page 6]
"type":; "deviceStatus",; "device":; "AS7341_Sensor_Device",; "timestamp":; "status":; "as7341_led":; true,; "as7341_bright":; "uv_led":; false,; "uv_bright":; "buzzer":; "sensor":; "stream_mode":; "fixed",; "stream_paused":; "packet_count":; "interval":; "current_count":; "target_count":; "remaining":

Status Field Description:
as7341_led : AS7341 LED on/off status
as7341_bright : AS7341 LED brightness (1-20)
uv_led : UV LED on/off status
uv_bright : UV LED brightness (1-20)
buzzer : Buzzer on/off status
sensor : Sensor initialization status
stream_mode : Data stream mode ("continuous" | "fixed")
stream_paused : Data stream pause status
packet_count : Total packet count
interval : Data stream interval (ms)
current_count : Current stream count
target_count : Target stream count
remaining : Remaining count
8. Connection Status Notifications

8.1 Connection Established Notification

{
"type": | "connection",
"status": | "connected",
"device": | "AS7341_Sensor_Device",
"timestamp": | 1234567890,
"ip": | "192.168.1.100",
"rssi": | -65,
"status": | {
"as7341_led": | true,
"as7341_bright": | 12,
"uv_led": | true,
"uv_bright": | 8,
"buzzer": | true,
"sensor": | true
}
}

### 8.2 Connection Disconnected Notification

{
"type": | "connection",
"status": | "disconnected",
"device": | "AS7341_Sensor_Device",
"timestamp": | 1234567890,
"status": | {
"as7341_led": | true,
"as7341_bright": | 12,
"uv_led": | true,
"uv_bright": | 8,
"buzzer": | true,
"sensor": | true
}
}

## 9. Completion Notifications
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

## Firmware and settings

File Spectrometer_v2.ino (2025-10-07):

#include <U8g2lib.h>
#include <Bounce2.h>
#include "DFRobot_AS7341.h"
#include <Ticker.h>
#include <EEPROM.h>
#include <WiFi.h>
#include <WiFiClient.h>
#include <IPAddress.h>
#include <ArduinoJson.h>
#include <WiFiServer.h>
#include <WiFiUdp.h>

// WiFi配置参数
#define WIFI_SSID_MAX_LEN 32
#define WIFI_PASS_MAX_LEN 64
#define IP_ADDR_MAX_LEN 16
#define TARGET_PORT 6677
#define WIFI_RECONNECT_DELAY 5000
#define TASK_WATCHDOG_TIMEOUT 3000
#define WIFI_CONNECT_TIMEOUT 5000

// WiFi重连相关变量
unsigned long last_reconnect_attempt = 0;
#define WIFI_RECONNECT_INTERVAL 30000  // 增加重连间隔到30秒
uint8_t reconnect_attempt_count = 0;
#define MAX_RECONNECT_ATTEMPTS 3       // 减少最大重连尝试次数

// 添加连接状态跟踪
bool manual_reconnect_triggered = false;
unsigned long last_stable_connection = 0;
#define STABLE_CONNECTION_THRESHOLD 10000  // 10秒稳定连接阈值

// JSON指令相关定义
#define COMMAND_PORT 6688
#define DATA_STREAM_PORT 6699
#define JSON_BUFFER_SIZE 512
#define MIN_DATA_STREAM_INTERVAL 400

// 数据流发送模式控制变量
typedef enum {
    STREAM_MODE_CONTINUOUS = 0,    // 持续发送
    STREAM_MODE_FIXED_COUNT        // 指定次数发送
} StreamMode_t;

StreamMode_t current_stream_mode = STREAM_MODE_CONTINUOUS;
uint32_t stream_count_target = 0;      // 目标发送次数
uint32_t stream_count_current = 0;     // 当前已发送次数
bool stream_paused = false;            // 发送暂停状态

// 添加响应队列机制
#define RESPONSE_QUEUE_SIZE 5
String responseQueue[RESPONSE_QUEUE_SIZE];
int responseQueueHead = 0;
int responseQueueTail = 0;
bool responseQueueFull = false;

// 设备状态更新队列
#define STATUS_QUEUE_SIZE 3
bool statusUpdatePending = false;
unsigned long lastStatusUpdateTime = 0;
#define STATUS_UPDATE_COOLDOWN 1000  // 状态更新冷却时间1秒

bool completionNotificationPending = false;

// EEPROM存储地址映射
#define EEPROM_SIZE 256
#define ADDR_INIT_FLAG    0
#define ADDR_AS7341_LED   1
#define ADDR_AS7341_BRIGHT 2
#define ADDR_UV_LED       3
#define ADDR_UV_BRIGHT    4
#define ADDR_BUZZER_EN    5
#define ADDR_BUZZER_VOL   6
#define ADDR_WIFI_ENABLE  7
#define ADDR_WIFI_SSID    8
#define ADDR_WIFI_PASS   40
#define ADDR_FIXED_IP    104
#define ADDR_TARGET_IP   120

// 硬件配置
#define OLED_SCL 6
#define OLED_SDA 7
#define KEY_UP 3        
#define KEY_SEL 2       
#define KEY_DOWN 4      
#define UV_LED_PIN 1    
#define BUZZER_PIN 5    

// 蜂鸣器参数
#define BUZZER_FREQ 2000
#define BUZZER_BEEP_DURATION 100
#define BUZZER_VOL_MAX 10
#define BUZZER_VOL_TO_PWM(vol) map(vol, 1, BUZZER_VOL_MAX, 25, 255)

// 按键长按时间阈值(ms)
#define LONG_PRESS_THRESHOLD 300

// 内存优化配置
#define MAX_STR_LEN 32
#define SPECTRAL_BUF_LEN 8
char str_buf[MAX_STR_LEN];
uint16_t temp_spectral[SPECTRAL_BUF_LEN];

// ========== 系统模式定义 ==========
typedef enum {
    SYSTEM_MODE_LOCAL = 0,    // 本地模式
    SYSTEM_MODE_DATA_STREAM   // 数据流模式
} SystemMode_t;

SystemMode_t current_system_mode = SYSTEM_MODE_LOCAL;
bool mode_transition_in_progress = false;

// 数据流模式状态变量
bool data_stream_mode_active = false;
bool target_server_connected = false;
unsigned long last_target_connect_attempt = 0;
#define TARGET_CONNECT_RETRY_INTERVAL 10000

// 定时器对象
Ticker keyScanTicker;
Ticker buzzerStopTicker;
Ticker wifiReconnectTicker;
Ticker taskWatchdogTicker;
Ticker dataStreamTicker;

// 按键扫描间隔
#define KEY_SCAN_INTERVAL 10

// 传感器读取控制
unsigned long last_sensor_read = 0;
#define SENSOR_READ_INTERVAL 200

// 全局对象
U8G2_SSD1306_128X64_NONAME_F_SW_I2C u8g2(
  U8G2_R0, OLED_SCL, OLED_SDA, U8X8_PIN_NONE
);
Bounce btn_up = Bounce();
Bounce btn_sel = Bounce();
Bounce btn_down = Bounce();
DFRobot_AS7341 as7341;
WiFiClient targetClient;  // 目标服务器TCP连接

// 状态变量
bool as7341_init_ok = false;
const char* main_menu[] = {
  "1. AS7341 Control", "2. UV LED Control", 
  "3. Buzzer Control", "4. WiFi Settings", "5. Exit"
};
const int MENU_COUNT = 5;
const int VISIBLE_ITEMS = 4;
const int TOTAL_PAGES = 3;
uint16_t spectral_data[SPECTRAL_BUF_LEN] = {0};
uint8_t current_page = 1;
bool in_spectral_mode = true;
int current_menu = 0;
int scroll_offset = 0;
bool in_submenu = false;
bool menu_updated = true;

// 按键相关变量
unsigned long sel_press_start = 0;
unsigned long up_press_start = 0;    
unsigned long down_press_start = 0;  
bool sel_is_pressing = false;
bool up_is_pressing = false;         
bool down_is_pressing = false;       
bool long_press_triggered = false;
bool up_long_triggered = false;      
bool down_long_triggered = false;    
bool sel_was_pressed = false;

// AS7341 LED控制变量
uint8_t as7341_led_bright = 10;
bool as7341_led_state = false;
uint8_t as7341_submenu_type = 0;

// UV灯控制变量
uint8_t uv_led_bright = 10;
bool uv_led_state = false;
uint8_t uv_submenu_type = 0;
#define UV_BRIGHT_TO_PWM(bright) map(bright, 1, 20, 0, 255)

// 蜂鸣器控制变量
bool buzzer_enable = true;
uint8_t buzzer_volume = 5;
uint8_t buzzer_submenu_type = 0;
bool buzzer_beeping = false;

// WiFi相关变量
char wifi_ssid[WIFI_SSID_MAX_LEN] = {0};
char wifi_pass[WIFI_PASS_MAX_LEN] = {0};
char fixed_ip[IP_ADDR_MAX_LEN] = {0};
char target_ip[IP_ADDR_MAX_LEN] = {0};
bool wifi_enable = false;
bool wifi_connected = false;
bool wifi_connecting = false;
uint8_t wifi_submenu_type = 0;
bool wifi_editing_switch = false;
bool wifi_task_running = false;
bool connection_notified = false;
unsigned long last_task_activity = 0;
unsigned long task_start_time = 0;
const char* current_task_name = "";

// WiFi编辑相关变量
bool editing_wifi_ssid = false;
bool editing_wifi_pass = false;
bool editing_fixed_ip = false;
bool editing_target_ip = false;
int wifi_edit_pos = 0;
char wifi_edit_buffer[WIFI_PASS_MAX_LEN] = {0};
bool shift_pressed = false;

// 字符码盘
const char normal_char_set[] = " abcdefghijklmnopqrstuvwxyzABCDEFGHIJKLMNOPQRSTUVWXYZ0123456789.-_!@#$%";
const char ip_char_set[] = "0123456789.";
const int normal_char_set_size = sizeof(normal_char_set) - 1;
const int ip_char_set_size = sizeof(ip_char_set) - 1;
int current_char_index = 0;

// JSON指令和数据流相关变量
bool data_stream_enabled = false;
unsigned long last_data_stream_time = 0;
uint32_t data_stream_interval = 100;
WiFiServer commandServer(COMMAND_PORT);
WiFiUDP dataStreamUdp;
DynamicJsonDocument json_doc(JSON_BUFFER_SIZE);

// 数据流统计
uint32_t data_stream_packet_count = 0;
unsigned long data_stream_start_time = 0;

// 设备信息
const char* DEVICE_NAME = "AS7341_Sensor_Device";
const char* DEVICE_TYPE = "Spectral_Sensor";
const char* FIRMWARE_VERSION = "2.0.0";

WiFiClient currentCommandClient;
bool commandClientConnected = false;
unsigned long lastCommandActivity = 0;
#define COMMAND_TIMEOUT 30000


void init_local_mode() {
    Serial.println("初始化本地模式...");
    
    // 停止所有可能的定时器
    keyScanTicker.detach();
    taskWatchdogTicker.detach();
    dataStreamTicker.detach();
    delay(50);
    
    // 初始化按键扫描定时器
    keyScanTicker.attach_ms(KEY_SCAN_INTERVAL, []() {
        // 数据流模式下跳过所有按键处理
        if (data_stream_mode_active) {
            return;
        }

        // 正常模式下的按键处理
        btn_up.update();
        btn_sel.update();
        btn_down.update();

        // 优先处理WiFi编辑
        if (editing_wifi_ssid || editing_wifi_pass || editing_fixed_ip || editing_target_ip || wifi_editing_switch) {
            handle_wifi_editing();
            return;
        }

        // UP键处理
        if (btn_up.fell()) {
            Serial.println("UP pressed");
            buzzer_beep();
            
            if (in_spectral_mode) {
                current_page = (current_page == 1) ? TOTAL_PAGES : (current_page - 1);
                menu_updated = true;
            } else {
                if (in_submenu && current_menu == 0) {
                    if (as7341_submenu_type == 1) {
                        as7341_led_bright = min(20, as7341_led_bright + 1);
                        if (as7341_led_state && as7341_init_ok) {
                            as7341.controlLed(as7341_led_bright);
                        }
                        save_to_eeprom();
                        menu_updated = true;
                    } else if (as7341_submenu_type == 2) {
                        if (!as7341_led_state && as7341_init_ok) {
                            as7341_led_state = true;
                            as7341.enableLed(true);
                            as7341.controlLed(as7341_led_bright);
                            save_to_eeprom();
                            menu_updated = true;
                        }
                    }
                } else if (in_submenu && current_menu == 1) {
                    if (uv_submenu_type == 1) {
                        uv_led_bright = min(20, uv_led_bright + 1);
                        if (uv_led_state) {
                            analogWrite(UV_LED_PIN, UV_BRIGHT_TO_PWM(uv_led_bright));
                        }
                        save_to_eeprom();
                        menu_updated = true;
                    } else if (uv_submenu_type == 2) {
                        if (!uv_led_state) {
                            uv_led_state = true;
                            analogWrite(UV_LED_PIN, UV_BRIGHT_TO_PWM(uv_led_bright));
                            save_to_eeprom();
                            menu_updated = true;
                        }
                    }
                } else if (in_submenu && current_menu == 2) {
                    if (buzzer_submenu_type == 1) {
                        buzzer_volume = min(BUZZER_VOL_MAX, buzzer_volume + 1);
                        save_to_eeprom();
                        menu_updated = true;
                    } else if (buzzer_submenu_type == 2) {
                        if (!buzzer_enable) {
                            buzzer_enable = true;
                            buzzer_beep();
                            save_to_eeprom();
                            menu_updated = true;
                        }
                    }
                } else if (in_submenu && current_menu == 3) {
                    wifi_submenu_type = (wifi_submenu_type == 1) ? 6 : wifi_submenu_type - 1;  // 从5改为6
                    menu_updated = true;
                } else if (!in_submenu) {
                    current_menu = (current_menu - 1 + MENU_COUNT) % MENU_COUNT;
                    handle_scroll_offset();
                    menu_updated = true;
                }
            }
        }

        // DOWN键处理
        if (btn_down.fell()) {
            Serial.println("DOWN pressed");
            buzzer_beep();
            
            if (in_spectral_mode) {
                current_page = (current_page % TOTAL_PAGES) + 1;
                menu_updated = true;
            } else {
                if (in_submenu && current_menu == 0) {
                    if (as7341_submenu_type == 1) {
                        as7341_led_bright = max(1, as7341_led_bright - 1);
                        if (as7341_led_state && as7341_init_ok) {
                            as7341.controlLed(as7341_led_bright);
                        }
                        save_to_eeprom();
                        menu_updated = true;
                    } else if (as7341_submenu_type == 2) {
                        if (as7341_led_state && as7341_init_ok) {
                            as7341_led_state = false;
                            as7341.enableLed(false);
                            save_to_eeprom();
                            menu_updated = true;
                        }
                    }
                } else if (in_submenu && current_menu == 1) {
                    if (uv_submenu_type == 1) {
                        uv_led_bright = max(1, uv_led_bright - 1);
                        if (uv_led_state) {
                            analogWrite(UV_LED_PIN, UV_BRIGHT_TO_PWM(uv_led_bright));
                        }
                        save_to_eeprom();
                        menu_updated = true;
                    } else if (uv_submenu_type == 2) {
                        if (uv_led_state) {
                            uv_led_state = false;
                            analogWrite(UV_LED_PIN, 0);
                            save_to_eeprom();
                            menu_updated = true;
                        }
                    }
                } else if (in_submenu && current_menu == 2) {
                    if (buzzer_submenu_type == 1) {
                        buzzer_volume = max(1, buzzer_volume - 1);
                        save_to_eeprom();
                        menu_updated = true;
                    } else if (buzzer_submenu_type == 2) {
                        if (buzzer_enable) {
                            buzzer_enable = false;
                            if (buzzer_beeping) {
                                analogWrite(BUZZER_PIN, 0);
                                buzzer_beeping = false;
                                buzzerStopTicker.detach();
                            }
                            save_to_eeprom();
                            menu_updated = true;
                        }
                    }
                } else if (in_submenu && current_menu == 3) {
                    wifi_submenu_type = (wifi_submenu_type == 6) ? 1 : wifi_submenu_type + 1;  // 从5改为6
                    menu_updated = true;
                } else if (!in_submenu) {
                    current_menu = (current_menu + 1) % MENU_COUNT;
                    handle_scroll_offset();
                    menu_updated = true;
                }
            }
        }
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
void loop() {
    if (data_stream_mode_active) {
        // 数据流模式主循环
        loop_data_stream_mode();
    } else {
        // 本地模式主循环
        loop_local_mode();
    }
}

void loop_data_stream_mode() {
    unsigned long current_time = millis();
    static unsigned long last_command_check = 0;
    static unsigned long last_status_check = 0;
    static unsigned long last_connection_check = 0;
    static unsigned long last_data_send = 0;
    static unsigned long last_queue_process = 0;
    
    // 1. 首先检查并发送UDP数据（最高优先级）
    if (current_time - last_data_send >= data_stream_interval) {
        send_data_stream_packet();
        last_data_send = current_time;
    }
    
    // 2. 处理响应队列（中等优先级）
    if (current_time - last_queue_process > 50) { // 每50ms处理一次队列
        process_response_queue();
        process_status_update_queue();
        last_queue_process = current_time;
    }
    
    // 3. 定期检查目标服务器连接状态（每3秒）
    if (current_time - last_status_check > 3000) {
        if (!targetClient.connected()) {
            target_server_connected = false;
            Serial.println("目标服务器连接断开，尝试重连...");
            if (!connect_to_target_server()) {
                Serial.println("重连失败，继续尝试发送数据...");
            }
        }
        last_status_check = current_time;
    }
    
    // 4. 定期检查WiFi连接状态（每5秒）
    if (current_time - last_connection_check > 5000) {
        if (WiFi.status() != WL_CONNECTED) {
            wifi_connected = false;
            Serial.println("WiFi连接断开，退出数据流模式");
            exit_data_stream_mode();
            return;
        }
        last_connection_check = current_time;
    }
    
    // 5. 处理指令服务器（最低优先级）
    if (current_time - last_command_check > 100) {
        handle_command_server_data_stream_mode();
        last_command_check = current_time;
    }
    
    // 6. 更新显示（每500ms）
    static unsigned long last_display_update = 0;
    if (current_time - last_display_update > 500) {
        menu_updated = true;
        last_display_update = current_time;
    }
    
    if (menu_updated) {
        u8g2.clearBuffer();
        draw_data_stream_mode();
        u8g2.sendBuffer();
        menu_updated = false;
    }
    
    // 短暂延时，避免过于频繁的循环
    delay(2);
}

void loop_local_mode() {
    unsigned long current_time = millis();
    static unsigned long last_command_check = 0;
    static unsigned long last_sensor_check = 0;
    static unsigned long last_wifi_check = 0;
    static unsigned long last_reconnect_check = 0;
    static unsigned long last_queue_process = 0;
    
    // 1. 处理响应队列（高优先级）
    if (current_time - last_queue_process > 50) {
        process_response_queue();
        process_status_update_queue();
        last_queue_process = current_time;
    }
    
    // 2. 处理指令服务器
    if (current_time - last_command_check >= 10) {
        handle_command_server_local_mode();
        last_command_check = current_time;
    }
    
    // 3. 定期检查WiFi连接状态（每500ms）
    if (current_time - last_wifi_check >= 500) {
        check_wifi_connection_status();
        last_wifi_check = current_time;
    }
    
    // 4. 定期检查自动重连（每2秒）
    if (current_time - last_reconnect_check >= 2000) {
        check_auto_reconnect();
        last_reconnect_check = current_time;
    }
    
    // 5. OLED显示更新
    if (menu_updated) {
        u8g2.setPowerSave(0);
        u8g2.clearBuffer();
        
        if (in_spectral_mode) {
            draw_spectral_page_fast();
        } else {
            if (!in_submenu) {
                draw_main_menu_fast();
            } else {
                draw_submenu_fast();
            }
        }
        
        u8g2.sendBuffer();
        menu_updated = false;
    }
    
    // 6. 传感器数据读取
    if (in_spectral_mode && as7341_init_ok && 
        (current_time - last_sensor_read >= SENSOR_READ_INTERVAL)) {
        if (read_spectral_data()) {
            menu_updated = true;
        }
        last_sensor_read = current_time;
    }
    
    delay(2);
}

// ========== 其他必要函数（需要从原代码中保留） ==========

// 以下函数需要从你的原代码中保留，由于篇幅限制这里只列出函数声明：
// 工具函数
bool is_string_empty(const char* str) {
  if (!str || *str == '\0') return true;
  while (*str) {
    if (*str != ' ') return false;
    str++;
  }
  return true;
}

void safe_strcpy(char* dest, const char* src, size_t dest_size) {
  if (!dest || !src || dest_size == 0) return;
  size_t i;
  for (i = 0; i < dest_size - 1 && src[i] != '\0'; i++) {
    dest[i] = src[i];
  }
  dest[i] = '\0';
}

bool is_valid_ip_address(const char* ip) {
  if (is_string_empty(ip)) return false;
  
  IPAddress addr;
  return addr.fromString(ip);
}

// EEPROM函数
void init_eeprom() {
  EEPROM.begin(EEPROM_SIZE);
  delay(10);
  
  uint8_t init_flag = EEPROM.read(ADDR_INIT_FLAG);
  if (init_flag != 0xAA) {
    EEPROM.write(ADDR_INIT_FLAG, 0xAA);
    EEPROM.write(ADDR_AS7341_LED, as7341_led_state);
    EEPROM.write(ADDR_AS7341_BRIGHT, as7341_led_bright);
    EEPROM.write(ADDR_UV_LED, uv_led_state);
    EEPROM.write(ADDR_UV_BRIGHT, uv_led_bright);
    EEPROM.write(ADDR_BUZZER_EN, buzzer_enable);
    EEPROM.write(ADDR_BUZZER_VOL, buzzer_volume);
    EEPROM.write(ADDR_WIFI_ENABLE, wifi_enable);
    
    eeprom_write_string(ADDR_WIFI_SSID, "", WIFI_SSID_MAX_LEN);
    eeprom_write_string(ADDR_WIFI_PASS, "", WIFI_PASS_MAX_LEN);
    eeprom_write_string(ADDR_FIXED_IP, "", IP_ADDR_MAX_LEN);
    eeprom_write_string(ADDR_TARGET_IP, "", IP_ADDR_MAX_LEN);
    
    EEPROM.commit();
    Serial.println("EEPROM initialized with defaults");
  } else {
    as7341_led_state = EEPROM.read(ADDR_AS7341_LED);
    as7341_led_bright = constrain(EEPROM.read(ADDR_AS7341_BRIGHT), 1, 20);
    uv_led_state = EEPROM.read(ADDR_UV_LED);
    uv_led_bright = constrain(EEPROM.read(ADDR_UV_BRIGHT), 1, 20);
    buzzer_enable = EEPROM.read(ADDR_BUZZER_EN);
    buzzer_volume = constrain(EEPROM.read(ADDR_BUZZER_VOL), 1, BUZZER_VOL_MAX);
    wifi_enable = EEPROM.read(ADDR_WIFI_ENABLE);
    
    eeprom_read_string(ADDR_WIFI_SSID, wifi_ssid, WIFI_SSID_MAX_LEN);
    eeprom_read_string(ADDR_WIFI_PASS, wifi_pass, WIFI_PASS_MAX_LEN);
    eeprom_read_string(ADDR_FIXED_IP, fixed_ip, IP_ADDR_MAX_LEN);
    eeprom_read_string(ADDR_TARGET_IP, target_ip, IP_ADDR_MAX_LEN);
    
    if (!is_valid_ip_address(fixed_ip)) {
      memset(fixed_ip, 0, IP_ADDR_MAX_LEN);
    }
    if (!is_valid_ip_address(target_ip)) {
      memset(target_ip, 0, IP_ADDR_MAX_LEN);
    }
    
    Serial.println("EEPROM loaded saved settings");
  }
}

void save_to_eeprom() {
  EEPROM.write(ADDR_AS7341_LED, as7341_led_state);
  EEPROM.write(ADDR_AS7341_BRIGHT, as7341_led_bright);
  EEPROM.write(ADDR_UV_LED, uv_led_state);
  EEPROM.write(ADDR_UV_BRIGHT, uv_led_bright);
  EEPROM.write(ADDR_BUZZER_EN, buzzer_enable);
  EEPROM.write(ADDR_BUZZER_VOL, buzzer_volume);
  EEPROM.write(ADDR_WIFI_ENABLE, wifi_enable);
  
  eeprom_write_string(ADDR_WIFI_SSID, wifi_ssid, WIFI_SSID_MAX_LEN);
  eeprom_write_string(ADDR_WIFI_PASS, wifi_pass, WIFI_PASS_MAX_LEN);
  eeprom_write_string(ADDR_FIXED_IP, fixed_ip, IP_ADDR_MAX_LEN);
  eeprom_write_string(ADDR_TARGET_IP, target_ip, IP_ADDR_MAX_LEN);
  
  EEPROM.commit();
  Serial.println("Settings saved to EEPROM");
}

void eeprom_read_string(int start_addr, char* buffer, int max_len) {
  memset(buffer, 0, max_len);
  for (int i = 0; i < max_len; i++) {
    buffer[i] = EEPROM.read(start_addr + i);
    if (buffer[i] == '\0') break;
    if (buffer[i] < 32 || buffer[i] > 126) {
      buffer[i] = '\0';
      break;
    }
  }
  buffer[max_len - 1] = '\0';
}

void eeprom_write_string(int start_addr, const char* buffer, int max_len) {
  for (int i = 0; i < max_len; i++) {
    if (buffer[i] == '\0') {
      EEPROM.write(start_addr + i, '\0');
      break;
    }
    if (buffer[i] >= 32 && buffer[i] <= 126) {
      EEPROM.write(start_addr + i, buffer[i]);
    } else {
      EEPROM.write(start_addr + i, ' ');
    }
  }
}

// 蜂鸣器函数
void buzzer_stop_callback() {
  analogWrite(BUZZER_PIN, 0);
  buzzer_beeping = false;
  buzzerStopTicker.detach();
}

void buzzer_beep() {
  if (buzzer_enable && !buzzer_beeping) {
    buzzer_beeping = true;
    analogWrite(BUZZER_PIN, BUZZER_VOL_TO_PWM(buzzer_volume));
    buzzerStopTicker.attach_ms(BUZZER_BEEP_DURATION, buzzer_stop_callback);
  }
}

// 错误提示音
void buzzer_error() {
  if (buzzer_enable && !buzzer_beeping) {
    buzzer_beeping = true;
    analogWrite(BUZZER_PIN, BUZZER_VOL_TO_PWM(buzzer_volume));
    delay(50);
    analogWrite(BUZZER_PIN, 0);
    delay(50);
    analogWrite(BUZZER_PIN, BUZZER_VOL_TO_PWM(buzzer_volume));
    delay(50);
    analogWrite(BUZZER_PIN, 0);
    buzzer_beeping = false;
    buzzerStopTicker.detach();
  }
}
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
